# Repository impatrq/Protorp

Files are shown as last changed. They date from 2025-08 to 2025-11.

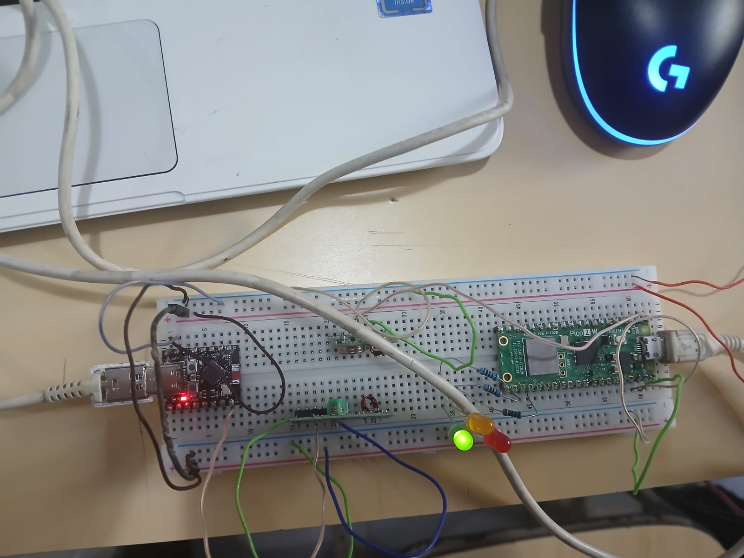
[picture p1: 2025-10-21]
fotos/pruebas en protoboard/prueba con una sola señal/ee414561-a399-4e3a-a274-134ad5745e3b.jpg

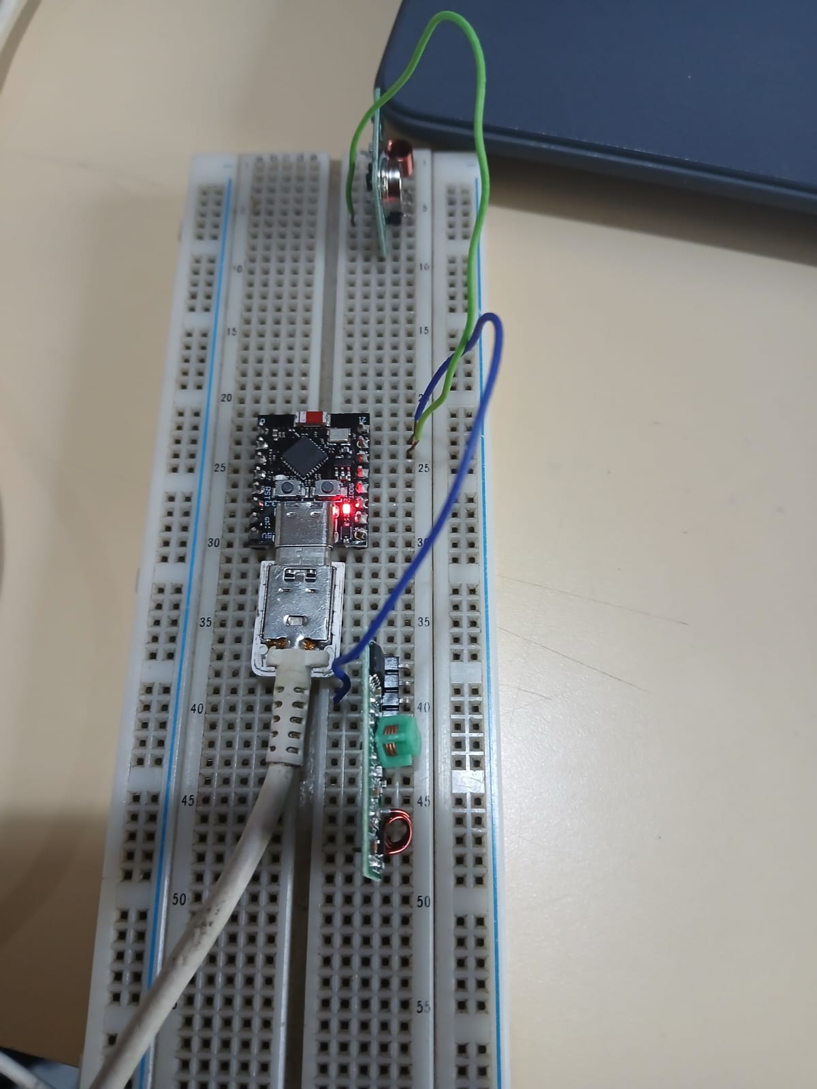
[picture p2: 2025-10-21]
fotos/pruebas en protoboard/prueba con una sola señal/pruebas con 2 señales/63338b9a-7119-42d7-b4c7-d0ca2e24c35b.jpg

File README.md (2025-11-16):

PROTORP 🚆

protorp y ahora sin png pero con png

🌟 Objetivo del Proyecto

PROTORP tiene como objetivo principal desarrollar sistemas de seguridad ferroviaria , como ATP (Automatic Train Protection) y ATS (Automatic Train Stop), a escala, para que pueda servir como entrenamiento y capacitacion para quien desee convertirse en señalero o maquinista, para que pueda ver las distintas situaciones que pueden ocurrir en las vias, sin tener que comprometer las formaciones reales ni sufrir accidentes durante el proceso de entrenamiento.

💡 ¿De dónde surgió la idea?

La idea de PROTORP nació de la necesidad de mejorar la seguridad y eficiencia en los sistemas ferroviarios, ademas de servir como capacitacion y entrenamiento, sin comprometer las formaciones reales ni sufrir accidentes, durante el proceso de entrenamiento, evitando costos asociados a refacciones y recuperacion de los afectados.

🛠️ Descripción del Proyecto

Nuestro proyecto incluye:
- Sistema ATS: Detiene automáticamente el tren si se salta una señal de advertencia.
- Sistema ATP: Controla la velocidad y la distancia entre trenes para evitar colisiones.
- Modelo a escala: Incluye señales y cambios de vía.

⚙️ Componentes a Utilizar
| Componente | Descripción | 
| Microcontroladores | ESP32| 
| LEDs | LEDs infrarrojos| 

🚀 Servicios que ofrece PROTORP
- Seguridad y prevención de accidentes: El sistema ATS actúa como un mecanismo de emergencia para frenar trenes que no respetan las señales.
- Eficiencia en el flujo de trenes: El sistema ATP organiza las formaciones para mantener distancias seguras y evitar demoras.
- Capacitación profesional: Permite entrenar maquinistas en un entorno seguro, reduciendo riesgos y costos.

👥 Equipo

Fernando Gonzalez: 





Santiago Vila: 


## 📬 Contacto


Pagina Web: https://protorp2025.netlify.app/

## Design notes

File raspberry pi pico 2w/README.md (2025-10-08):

**Comunicación RF entre Raspberry Pi Pico y ESP32**

Este repositorio se basa el desarrollo de un sistema de señalización ferroviaria, basado en comunicación por radiofrecuencia entre una Raspberry Pi Pico (a la cual va conectada un transmisor) y una ESP32 ( a la cuel se conecta un receptor). El objetivo es simular el estado de vías (LIBRE, PRECAUCIÓN, OCUPADO).

**¿Por qué se borró esta carpeta varias veces?**

Durante el proceso de testeo se realizaron varias modificaciones del código para la RASPBERRY y se elimino esta carpeta algunas veces. La razon principal es que pasamos de usar comunicacion entre una Raspberry en la locomotora y otra en la via, a cuna comunicacion usando una ESP32 en la locomotora y una Raspberry en la via y usando sensores RF433MHZ, por lo que los viejos codigos quedaron desactualizados 

Este README se creo con la finalidad de explicar porque se borro la carpeta varias veces y se eliminaron varios codigos. Esta carpeta contiene la libreria que se uso, los cambios importantes se realizaran en el codigo llamado main.py. La siguiente actualizacion en ese codigo se hara para incluir 2 transmisores y 2 receptores en la Raspberry.

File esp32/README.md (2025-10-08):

**Comunicación RF entre Raspberry Pi Pico y ESP32**

Este repositorio se basa el desarrollo de un sistema de señalización ferroviaria, basado en comunicación por radiofrecuencia entre una Raspberry Pi Pico (a la cual va conectada un transmisor) y una ESP32 ( a la cuel se conecta un receptor). El objetivo es simular el estado de vías (LIBRE, PRECAUCIÓN, OCUPADO).

**¿Por qué se borró esta carpeta varias veces?**

Durante el proceso de testeo se realizaron varias modificaciones del código para la ESP32 y se elimino esta carpeta algunas veces. Algunas razones son:

- Se pasó de una estructura básica de recepción a una más modular, con codificación de velocidad e ID.
- El receptor RF original con el que lo probamos tenía fallas, lo que llevó a problemas en la recepción y ajustes innecesarios en el código.
-  Se eliminaron versiones redundantes, pines mal asignados y funciones que no se usaban en la prueba actual.
- La ultima razon es que los codigos originales se hicieron para que la ESP32 y la raspberry se comunicaran por WIFI, pero la gracia es que se manden los datos por los transmisores y receptores de 433MHZ para poder usarlos como baliza y sensar el paso del tren cuando pasa por la via, y que la raspberry se comunique con WIFI y poder mostrar toda la informacion que tienen las señales conectadas  a las raspberrys en la pagina web     

Este README se creo con la finalidad de responder a esa pregunta. A partir de ahora se añadiran las librerias que se usaron y como probar el codigo, pero los cambios importantes se realizaran en el codigo llamado main.py.
El codigo qmain.py que esta actualmente, a fecha de creado este Readme, se hizo de esta manera para probar un transmisor en la Raspberry y un receptor en la ESP32. El siguiente cambio que se hara en el codigo sera para que el ESP32 tenga un transmisor y un receptor y la Raspberry tenga 2 transmisores y 2 receptores.

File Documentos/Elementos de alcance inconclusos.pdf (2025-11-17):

ELEMENTOS DE ALCANCE INCONCLUSOS

Nuestra principal problematica fue que iniciamos un poco tarde el desarrollo del proyecto ya que, en primera instancia, nos contactamos con un trabajador y un pasante de la empresa SIEMENS MOBILITY. Contabamos con que la empresa nos iba a conceder los fondos para el proyecto, pero la fundacion de la empresa rechazo darle los fondos a las personas con las que nos contactamos y ellos tardaron mucho tiempo en avisarnos. Por lo mismo, se nos dificulto la adquisicion de la locomotora y las vias.

El siguiente problema fue que compramos sensores RF de 433mhz. Hicimos varias pruebas entre ellos con distintos lenguajes y plataformas de programacion(Arduino, Thonny y VScode), ya sea con ESP32 o con Raspberry Pi en Thonny, y el principal problema fue que el transmisor mandaba el mensaje pero el receptor nunca lo recibia, a pesar de estar a una minima distancia, por lo que no pudimos demostrar el funcionamiento de los semaforos y tampoco pudimos hacer que las raspberrys mandaran el estado de los semaforos a la pagina web (ya que al principio queriamos que en la pagina hubiera una seccion que mostrara las distintas formaciones que estaban en el hardware.)

Por ultimo, creemos que no pudimos trabajar mejor en solucionar estos errores debido al numero de integrantes del equipo(2), lo que hizo dificil la distribucion y atencion de las tareas (un ejemplo de esto es nuestra pagina de instagram, en la cual subiamos mayormente historias pero no muchas publicaciones).

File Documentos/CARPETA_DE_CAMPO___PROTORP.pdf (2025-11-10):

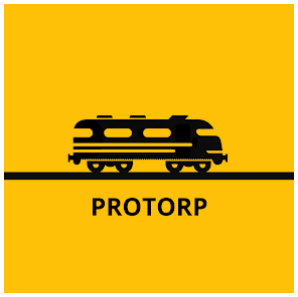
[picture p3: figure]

# PROTORP

## Carpeta de Campo

## Año de desarrollo: 2025

## E.E.T. Nº7 de Quilmes

Sitio web: https://protorp2025.netlify.app/

Trello: https://trello.com/b/dudjmzhY/kanban

GitHub: https://github.com/impatrq/Protorp

Redes sociales: @protorp25 (https://www.instagram.com/protorp25/)

Escuela de Educación Técnica Nº7 “Taller Regional Quilmes” Especialidad: Electrónica

Año lectivo: 2025

## Índice

1. Equipo | 2
2. Objetivo del Proyecto PROTORP | 2
Objetivo del Proyecto PROTORP | 2
Documentación Día a Día | 3

## 1. Equipo

## Integrantes del proyecto PROTORP

Joaquín Gonzalez Nogueira | Santiago Nicolás Vila

## 2. Objetivo del Proyecto PROTORP

El proyecto PROTORP (Protección y Regulación de Trenes mediante Organización y Respuesta Programada) tiene como objetivo principal el desarrollo de un sistema automático de protección ferroviaria (ATP) y un sistema de frenado automático (ATS) a escala, combinando hardware y software en un entorno educativo.
El propósito es crear una maqueta funcional que simule un circuito ferroviario real, con señales, cambios de vía, sensores de ocupación y control mediante microcontroladores como ESP32 y Raspberry Pi.
Además, el sistema busca representar cómo la tecnología puede mejorar la seguridad, eficiencia y automatización en el transporte ferroviario, estableciendo un puente entre la educación técnica y las soluciones tecnológicas reales aplicadas al ámbito ferroviario argentino.

## PROYECTO PROTORP: DOCUMENTACIÓN DÍA A

## DÍA

### ABRIL

14/4: Creamos la cuenta de instagram y Santiago empezo a comunicarse con sponsors. 15/4: Joaquin empezo con la programación de la página web y Santiago con la búsqueda de sponsors.
16/4: Joaquin continuo con la programación de la pagina web, y Santiago con búsqueda de sponsors.
17-20/4: Feriado
21/4: Joaquin continuo con el desarrollo de la pagina web
23/4: Joaquin continuo con la pagina web
30/4: Joaquin continuo con la pagina web

### MAYO

7/5: Joaquin continuo con la pagina web
9/5: Joaquin continuo con la programación de la pagina web
Semana del 12/5 a 18/5: Ambos tuvimos una reunion con SIEMENS, leimos la documentación y Joaquin continuo la programación de la pagina web
Semana 19/5 a 25/5: Tuvimos una segunda reunion con SIEMENS para hablar sobre nuestras dudas y Joaquin termino la programación de la pagina web, consiguio un link en Netlify.app y Santiago la subio al Instagram
Semana 26/5 a 1/6: Santiago realizo un diagrama del funcionamiento de las vías y Joaquin añadio un poco de información a la pagina ya que recibimos comentarios de que faltaba información

### JUNIO

Semana 2/6 a 8/6: Esta semana nos dedicamos a preguntarle a distintos profes sobre que componentes usar y a empezar con unas reformas en la pagina web
Semana 9/6 a 15/6: Santiago realizo la lista de materiales y la mando a la empresa, mientras Joaquin siguio con las reformas en la pagina web
Semana 16/6 a 22/6: Joaquin instalo Blender y aprendio a usarlo para poder realizar el modelo 3D de la señalizacion de los cambios de via
Semana 23/6 a 29/6: Joaquin realizo el modelo 3D de la primera señal y la subio al Github como STL

### JULIO

16/7: Tuvimos una reunion sobre los avances del proyecto. Nos sugirieron trabajar durante el receso invernal para ganar tiempo y pedirle los componentes a cooperadora. 18/7: Fuimos a pedir 2 Raspberrys Pi Pico 2W y 2 modulos RF de 433mhz a Cooperadora. Tambien nos prestaron resistencias y LEDs del pañol.
Receso Invernal: Joaquin estuvo haciendo simulaciones en Wokwi, que luego serian probadas en agosto.

### AGOSTO

4/8: Joaquin probo en Wokwi el modulo de comunicacion de tren - via y semaforos con 2 ESP32 y 3 leds.
5/8: Joaquin probo en Wokwi el modulo de sensor de ocupacion de via con un ESP32 y un led
6/8: Joaquin probo en Wokwi el funcionamiento de la señalización ferroviaria con un ESP32, un servo, un boton y 3 leds
8/8: Joaquin actualizo el sensor de ocupacion. Desde cooperadora nos mandaron llas 2 Raspberrys que pedimos. Santiago subio una historia agradeciendole a cooperadora por las Raspberry y Joaquin instalo la configuracion de micropython en vscode para configurar la Raspberry.
11/8: Empezamos a hacer el diagrama eléctrico mientras inicializabamos la Raspberry en VScode.
13/8: A la mañana empezamos el curso de drones. A la tarde visitamos Retiro donde nos dieron una capacitacion y nos permitieron recorrer los andenes que estan en obra. 18/8: Joaquin empezo a preparar el codigo para que funcione el wifi de la Raspberry que ira en la via.
20/8: Este dia, a pesar de tener practicas profesionalizantes, no pudimos hacer nada porque se fue la luz y no pudimos cargar nuestras compus. Este dia tambien llegaron los sensores RF de 433 mhz de parte de cooperadora, entonces fuimos a retirarlos.
21/8: Joaquin termino de hacer el codigo de la raspberry que iria en la locomotora y probamos la comunicacion wifi entre ambas raspberry
27/8: Tuvimos el curso de dron
28/8: Tratamos de probar la raspberrys en fisico pero no tenian las patitas. Joaquin actualizo el codigo entre la Raspberry y la locomotora de la via

### SEPTIEMBRE

1/9: Santiago empezó a hacer un segundo modelo 3D de las señales ferroviarias ya que el primero tenia errores en el modelo
2/9: Santiago continuo con el segundo modelo 3D de las señales
3/9: Tuvimos curso de dron
4/9: Este dia ambos faltamos pero mandamos a imprimir una nota para llevar al Ferroclub Escalada y se la hicimos firmar al vicedirector Arguello
6/9: Este dia, a pesar de ser fin de semana y no tener practicas profesionaliantes, fuimos al Ferroclub Escalada con la nota. Este dia no habiamos llevado los componentes y nos dijeron que debian consultarle a la fundacion del Ferroclub por los materiales, asi que nos pidieron que volvieramos la siguiente semana con los componentes para darles una mejor explicacion de como iban a ir los componentes en el circuito
9/9: Santiago termino el segundo modelo 3D de las señales ferroviarias
10/9: Fuimos al curso de dron
13/9: Este dia volvimos al Ferroclub Escalada junto con los componentes. Les explicamos mejor el funcionamiento del circuito y como iban a ir montados los componentes. Nos dijeron que volvieramos la otra semana con otra nota para que nos den el material, pero nos confirmaron que nos iban a prestar una locomotora y un par de vías
16/9: Hicimos una lista de materiales y fuimos a pedirlos a cooperadora.
17/9: A la mañana estuvimos en el curso de drones. En la tarde Joaquin empezo a realizar el banner y Santiago el primer diseño de la placa en KiCad.
18/9: Joaquin termino de hacer el banner y Santiago continuo con el diseño de la placa en kicad
19/9: Santiago continuo haciendo el diseño de la placa en KiCad y le añadio una base al modelo en 3D
20/9: Santiago volvio al Ferroclub Escalada y le proporcionaron el tren y un par de vias 22/9: Probamos la corriente en las vias que nos proporciono el Ferroclub Escalada 23/9: Santiago soldao las patitas al ESP32 y continuo con el modelo en Kicad
24/9: Santiago finalizo el diseño en Kicad. Tambien, Joaquin empezo a hacer el codigo en una de las compus de la escuela ya que su compu andaba mal. Joaquin estuvo toda la mañana en el aula del profesor Montoni haciendo el codigo. A la tarde, el profesor Garabato nos proporciono mas vias, cambios de via y locomotoras para probar el circuito en fisico. Dedicamos un rato a ver que nos servia y que le podiamos devolver y luego Joaquin eempezo a instalar las librerias necesarias en Thonny y VScode para probar el codigo
25/9: Joaquin trato de probar el codigo del ESP32 en ARDUINO IDE pero no funciono. Tambien empezamos a limpiar las vias que nos dio el profesor Garabato y armamos el circuito para probar la corriente y verificar que el tren andara correctamente sobre las vias.
26/9: Continuamos limpiando las vias con virulana y alcohol. Este dia tambien nos mudamos a la jaula del fondo ya que se nos hacia incomodo armar y desarmar el circuito cada vez que queriamos probarlo, asi que decidimos llevar 2 mesas a la jaula y dejar las vias armadas ahi. Tambien Joaquin trato de probar la comunicacion wifi entre esp32 y raspberry en una de las compus de la jaula pero estas no tenian internet, asi que decidimos tratar de probarla en la comu de Santiago pero ahi tampoco funciono.
30/9: Este dia, Joaquin trato de probar por ultima vez el codigo en su compu con Platformio. El codigo se subio correctamente al esp32 pero al momento de abrir el serial monitor, este tardaba mucho en cargar o no mostraba nada. Finalmente, decidio probar el codigo del ESP32 y el de la Raspberry en Thonny

### OCTUBRE

1/10: A la mañana, pasamos el codigo de la Raspberry a Thonny y como aun no teniamos programada la esp32 para que mandara el estado de las vias, probamos mandandole mensajes desde una app llamada MyMQTT. A la tarde, Joaquin modifico el codigo del ESP32 para que mandara el estado de las vias.
2/10: Joaquin modifico el codigo de ambos componentes para incluir los leds y los sensores RF de 433mhz. Tratamos de probar el circuito en fisico pero nuestro cable no transmitia datos, entonces decidimos que lo probariamos el 7/10. Este dia, Santiago hizo la impresion del primer semaforo en 3D. El modelo 3D tenia una base aparte, asi que luego de imprimirlo en 3D, Santiago lijo y quito todo el sobrante, luego separo la base y la pego con la gotita. Por ultimo, luego de la escuela, fuimos a lo del señor Daniel Raley para conseguir mas vias rectas y otros 2 cambios de via. Nos proporciono un par de vias pero no nos pudo proporcionar los cambios de via que nos faltaban.
6/10: Este dia armamos el circuito para probarlo en fisico, pero nos dimos cuenta de algo importante. Los codigos originales se hicieron para que la Raspberry y la ESP32 se comunicaran por wifi, pero la gracia es que los datos se manden por los sensores de 433mhz. Luego de darnos cuenta de eso, Joaquin empezo a modificar todo el codigo de nuevo. Este dia, Santiago imprimio el segundo semaforo
7/10: Este dia, Santiago imprimio el 3er y 4to semaforo. Joaquin busco las librerias para poder programar los sensores de 433mhz junto con la Raspberry en Thonny. Las librerias que encontro para los sensores no eran compatibles con micropython, entonces le pidio a una IA que le cree una libreria para usar. Luego, empezo a programar nuevamente la ESP32 y la Raspberry con esta libreria. El codigo fue hecho para probar una sola señal 8/10: Este dia, Joaquin termino de programar la Raspberry y la ESP32 y tratamos de probar el circuito en fisico. Al principio no funciono ya que uno de los transmisores estaba dañado, luego lo intercambiamos con otro transmisor y funciono. El transmisor mostraba un estado entre “LIBRE”, “PRECAUCION” y “OCUPADO” en el shell de Thonny con la Raspberry y cambiaba el led dependiendo del estado. La ESP32 captaba este estado con su receptor y lo mostraba en el shell de Thonny que este fue recibido junto con la

velocidad simulada.
9/10: Este dia, Joaquin cambio el codigo para que se probaran dos señales en lugar de solo una. Luego empezamos el circuito con un ESP32, una raspberry, 3 TX y 3 Rx en 3 protoboards para probar su funcionamiento pero se nos hizo tarde y no pudimos prrobarlo, asi que lo probamos el dia 13/10
10/10: Este dia Santiago fue a la casa de un vecino a conseguir los cambios de via y vias rectas faltantes.
13/10: Este dia volvimos a armar el circuito en fisico para probarlo. No anduvo correctamente debido a que habia algunos errores en el codigo, mayormente relacionados a la logica de funcionamiento entre los componentes, asi que Joaquin empezo a modificar el codigo nuevamente para respetar esa logica.
14/10: Joaquin continuo modificando el codigo de ambos componentes y Santiago modifico el modelo en blender para que esta vez el modelo tuviera 2 semaforos y se pudieran imprimir mas rápido. Este dia tambien fuimos a cooperadora a solicitar un doble puente h driver l298n y unos pines hembra. Tambien teniamos pensado empezar a imprimir la placa pero este dia no estaba el profesor Fabricio Carlassara, que es el dueño de la fresadora y del software, asi que no pudimos imprimirlas.
15/10: Joaquin termino de armar ambos códigos. A la tarde, quisimos armar el circuito nuevamente, pero la profesora Lara necesitaba los protoboards, asi que probamos el circuito al dia siguiente.
16/10: Este dia armamos el circuito por ultima vez. El codigo parecia funcionar pero se nos quemo la raspberry porque accidentalmente pusimos 10volts en la fuente. Decidimos dejar de armar el circuito en protoboard cada vez que ibamos a probarlo para evitar accidentes como estos y empezar a armar la placa. Tambien, Joaquin a modificar el codigo para poder manejar la esp32 por bluetooth.
17/10: Joaquin continuo modificando el codigo para controlar la esp32(locomotora) por bluetooth, aparte de adquirir la libreria ble_simple_peripheral.py que es necesaria para que el esp32 se anuncie como un dispositivo bluetooth. Este dia tambien llego el driver l298 n asi que fuimos a buscarlo a cooperadora.
20/10: A la mañana no pudimos hacer mucho debido a que no habia wifi. A a tarde, Joaquin continuo con el codigo, añadiendole la logica de control del motor e incluyendole el driver l298n
21/10: Este dia, el profesor Fabricio Carlassara nos aconsejo cambiar el diseño en Kicad para hacer modulos de 1 raspberry en vez de tenerlas todas en una sola placa. Santiago modifico el diseño en KiCad y tambien corto la placa de cobre en nueve partes. Mientras tanto, Joaquin se instalo la app nRF connect para mandarle una velocidad aleatoria all esp32 desde la app y verificar que apareciera en el Thonny. Esta app tambien tiene una opcion de lectura que muestra las velocidades aleatorias que genera la esp32 en la app. Tambien instalo la libreria uwebsockets en la raspberry para coordinarla con la pagina web. Santiago rediseño el banner ya que nos parecio que el que hicimos antes quedo obsoleto, además que el anterior estaba en 90x120 px, lo que hacia que fuera muy pequeño, asi que en la segunda version tratamos de que saliera con la mayor calidad posible. 22/10: Santiago imprimio los semaforos 11 y 12 en 3D. Tambien imprimio la primera placa y la dejamos lista para soldar. Este dia tambien enviamos el banner al profesor Palmieri y luego de la escuela fuimos a retirar los pines hembra que compramos.
23/10: Santiago abrio en Blender el modelo 3D de los semaforos normales y tomo sus bases. Luego, las exporto al modelo 3D de los semaforos de cambio de via y se las añadio a ese modelo para poder imprimirlas con el fin de que tengan el mismo soporte que los semaforos normales. Luego fuimos a imprimirlos. Mientras tanto, Joaquin se enfoco en ver ejemplos de años pasados para realizar el manual de usuario, carpeta tecnica y video de presentación de la mejor manera posible. Tambien nos comunicamos con nuestro patrocinador SIEMENS para ver si nos podian proporcionar manuales de usuario para usar de inspiracion.
24/10: Joaquin realizo la carpeta del manual de usuario y empezo a programar el nuevo codigo de la raspberry
27/10: Joaquin continuo realizando el codigo de la raspberry y Santiago modifico el modelo del semaforo del cambio de via. Luego, Santiago imprimio el 13vo y 14vo semaforo en 3D
28/10: Este dia, Santiago imprimio los semaforos 15 y 16. Joaquin continuo el codigo de la raspberry y empezo a armar el texto del manual de usuario
29/10: Este dia fuimos a hacer pasantias a la empresa NEWTON. A la tarde, Joaquin continuo con el codigo de la Raspberry y con el texto del manual de usuario. Santiago armo el tren con el puente H, soldo algunas Raspberrys y lijo los sobrantes de los semaforos que imprimimos
30/10: Este dia, Joaquin termino el manual de usuario del proyecto implementado en un entorno real, pero nos recomendaron cambiarlo para que sea la explicación de la maqueta. Joaquin empezo con el nuevo texto y siguio programando las raspberrys. Mientras tanto, Santiago empezo a grabar tomas para el video presentación
31/10: Joaquin termino e el manual de usuario de la maqueta y ambos grabamos los audios para el video presentación. Santiago hizo todas las placas y se encargo de editar el video.

### NOVIEMBRE

3/11: Santiago agujereo todas las placas e hizo el modelo 3D de la cajita del motor. 4/11: Santiago armo todos los semaforos, con sus leds y sus cables. Joaquin empezo a hacer la carpeta tecnica.
5/11: A la mañana fuimos a NEWTON. A la tarde, Joaquin continuo con la carpeta tecnica y probamos el funcionamiento de la ESP32 y el driver por Bluetooth, observamos que al mandarle un valor se movia un poco y despues se detenia, decidimos cambiar los cables al dia siguiente. Mientras, nos pidieron rehacer el video presentación, asi que Santiago grabo nuevas tomas y se encargo de editar el video.
6/11: Probamos nuevamente el funcionamiento de la ESP32 por Bluetooth. Seguia pasando lo mismo que el dia anterior. Entonces, Joaquin trato de hacer una app por RemoteXY de Arduino, pese a que no le haya funcionado para programar antes. Instalo todas las librerias necesarias y se puso a hacer la app. Mientras, Santiago agujereo mas placas y probo el funcionamiento de uno de los semaforos junto con la Raspberry, que ya tenia el codigo cargado
7/11: A la mañana, Joaquin trato de seguir programando la app en arduino. Mientras, vino el profesor Medina y trato de ayudarnos a ver cual podia ser el problema. Santiago trato de armar nuevamente el circuito junto con el profe, mientras Joaquin le cargaba el codigo antiguo de Thonny al ESP32. Cuando lo probamos nuevamente, Santiago se dio cuenta que habia puesto la corriente de las vias al reves, entonces al invertirlo y mandarle valores por la app nRF connect, anduvo normalmente. Hicimos un par de pruebas mas pero la ESP32 se calento excesivamente. Le preguntamos al profesor Medina cual podria haber sido el problema, y junto con el verificamos que la ESP32 se habia quemado. Decidimos probar el codigo con la otra ESP32 que teníamos pero esta tambien estaba quemada, entonces Santiago pidio 2 ESP32 que llegarian el dia siguiente. Mientras, Santiago siguio armando las placas y los semaforos y Joaquin continuo con la carpeta tecnica y se puso a actualizar la carpeta de campo.

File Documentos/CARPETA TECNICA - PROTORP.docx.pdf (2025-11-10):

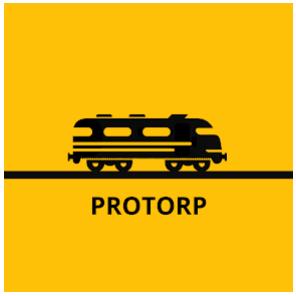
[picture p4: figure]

## PROTORP

## Carpeta técnica

Año de desarrollo: 2025

E.E.T. Nº7 de Quilmes

Sitio web: https://protorp2025.netlify.app/

Trello: https://trello.com/b/dudjmzhY/kanban

GitHub: https://github.com/impatrq/Protorp

Escuela de Educación Técnica Nº7 “Taller Regional Quilmes”

Especialidad: Avionica

## 1. Presentación del equipo

### 1.1 Integrantes del proyecto PROTORP

Joaquín González Nogueira

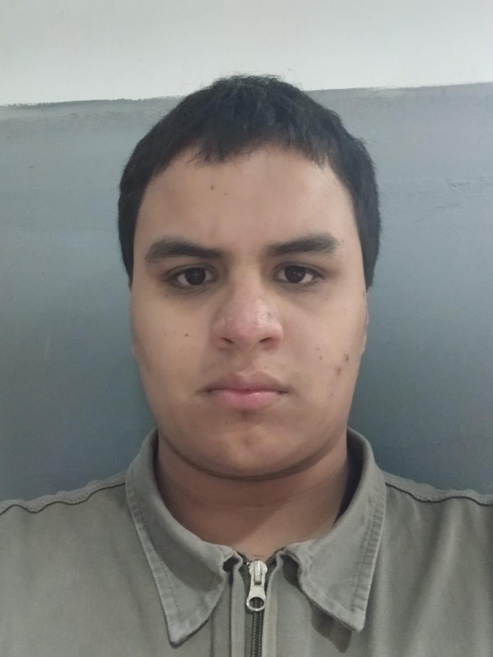
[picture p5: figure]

Santiago Nicolás Vila

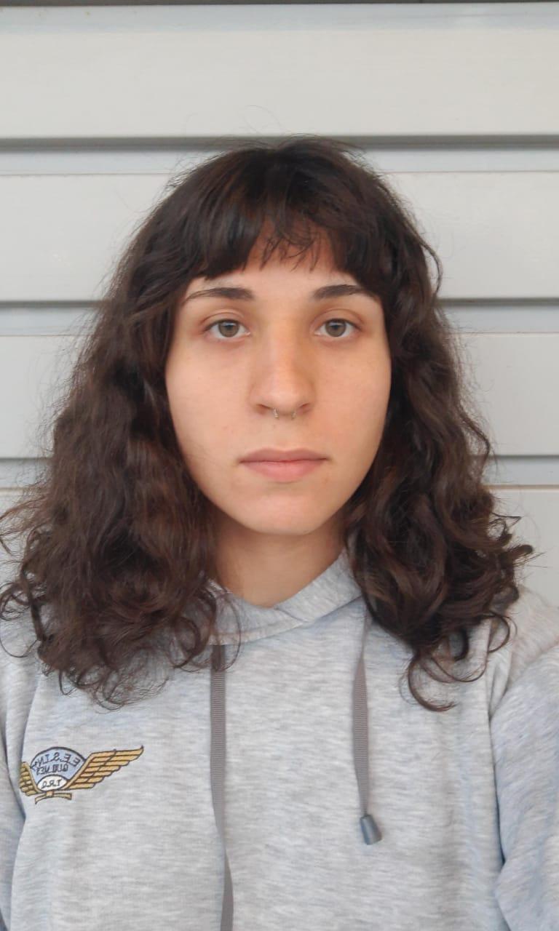
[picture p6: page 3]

### 1.2 Tiempo del proyecto

Cada integrante trabajó un promedio de 12 horas semanales en el proyecto.

## 2. Introducción

### 2.1 Objetivo del proyecto

PROTORP consiste en el desarrollo de los sistemas ATS (Automatic Train Stop) y ATP (Automatic Train Protection) a escala. Este proyecto tiene dos objetivos principales:

- Controlar las formaciones que circulan sobre la vía y la forma en la que se respetan los espacios para cada una, mejorando la seguridad del personal y reduciendo la posibilidad de errores humanos.
- Servir como entrenamiento para aspirantes a maquinistas, recreando distintas situaciones ferroviarias en un entorno seguro.

### 2.2 Descripción y Funcionamiento

La solución consiste en una maqueta ferroviaria que integra los principios de los sistemas ATS y ATP. El circuito reproduce un entorno ferroviario a escala, permitiendo controlar la circulación de los trenes y garantizar la seguridad de la operación.

### 2.4 Segmento destino y alcance

El proyecto está orientado principalmente a personas que deseen comprender el funcionamiento de los sistemas ATS y ATP en un entorno educativo y controlado. En cuanto al alcance geográfico, el sistema se proyecta a nivel nacional, dado que estos sistemas aún no se implementan ampliamente en Argentina.

## 3. Sistemas embebidos

### 3.1 Microcontroladores y microprocesadores utilizados

ESP32 (MicroPython)

Función: Controla la locomotora, gestiona el movimiento mediante un driver PWM, recibe comandos por BLE (NRF Connect) y transmite datos de velocidad y estado hacia las Raspberry Pi Pico mediante UART. Además, recibe señales RF433 MHz desde la vía para frenar o reducir la velocidad según la condición del tramo.

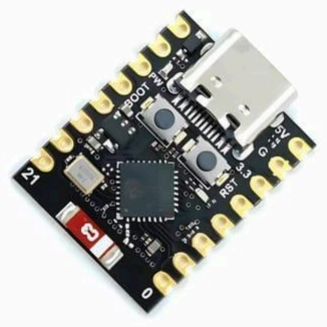
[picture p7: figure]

Raspberry Pi Pico 2W (MicroPython)

Función: Supervisa sensores de ocupación, controla semáforos (LEDs), comunica estados por Wi-Fi y envía datos a la locomotora vía RF433 MHz.

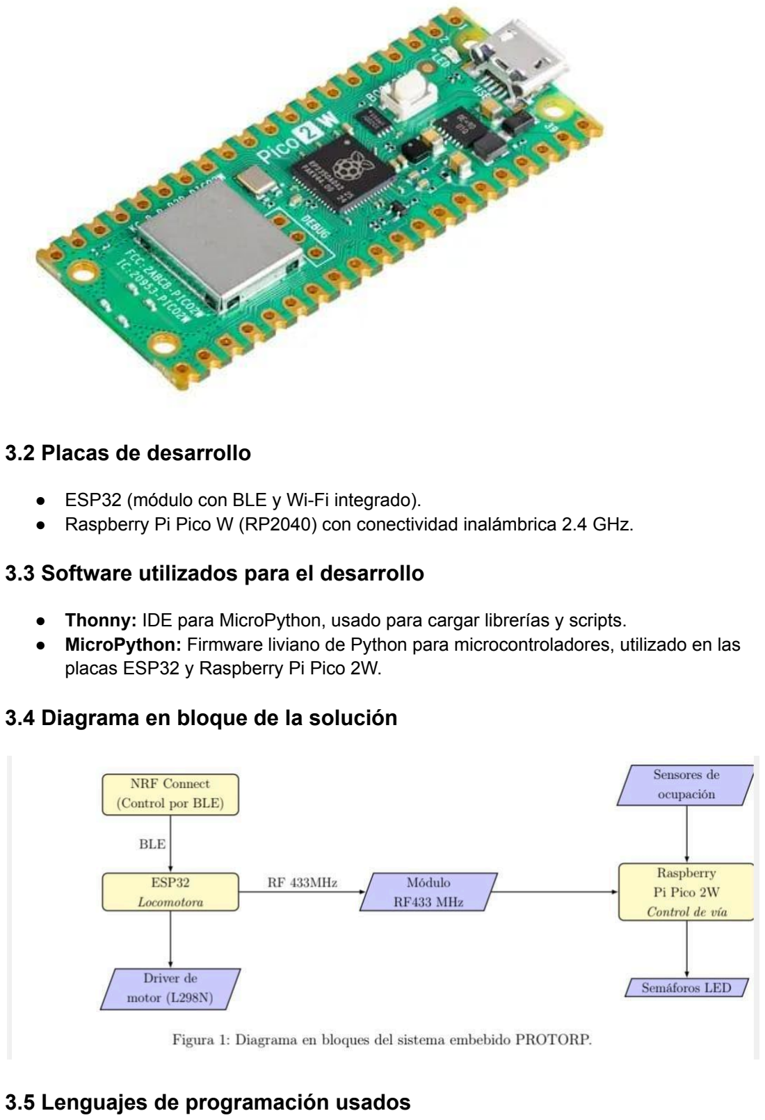
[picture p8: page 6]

### 3.2 Placas de desarrollo

- ESP32 (módulo con BLE y Wi-Fi integrado).
- Raspberry Pi Pico W (RP2040) con conectividad inalámbrica 2.4 GHz.

### 3.3 Software utilizados para el desarrollo

- Thonny: IDE para MicroPython, usado para cargar librerías y scripts.
- MicroPython: Firmware liviano de Python para microcontroladores, utilizado en las placas ESP32 y Raspberry Pi Pico 2W.

### 3.4 Diagrama en bloque de la solución

### 3.5 Lenguajes de programación usados

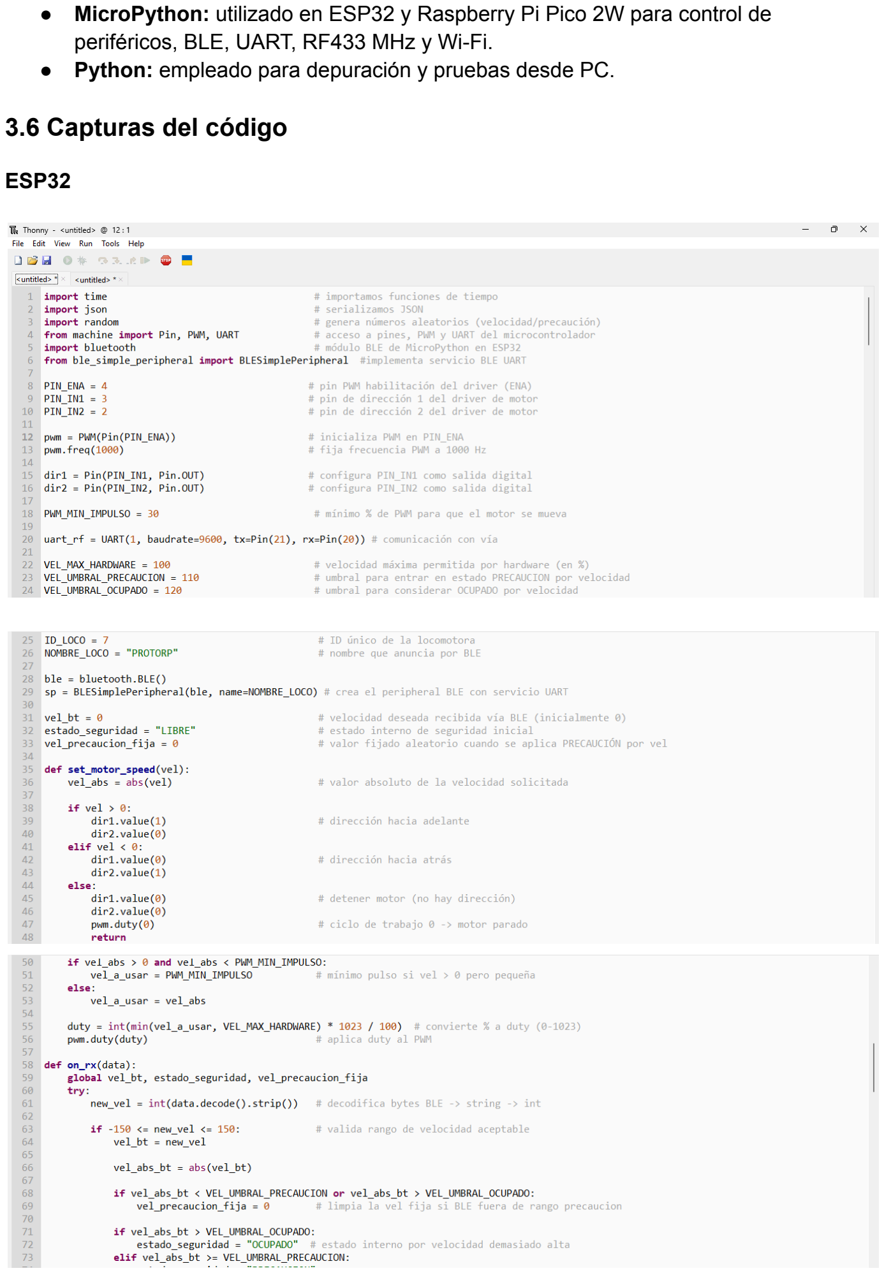
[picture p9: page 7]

- MicroPython: utilizado en ESP32 y Raspberry Pi Pico 2W para control de periféricos, BLE, UART, RF433 MHz y Wi-Fi.
- Python: empleado para depuración y pruebas desde PC.

### 3.6 Capturas del código

ESP32

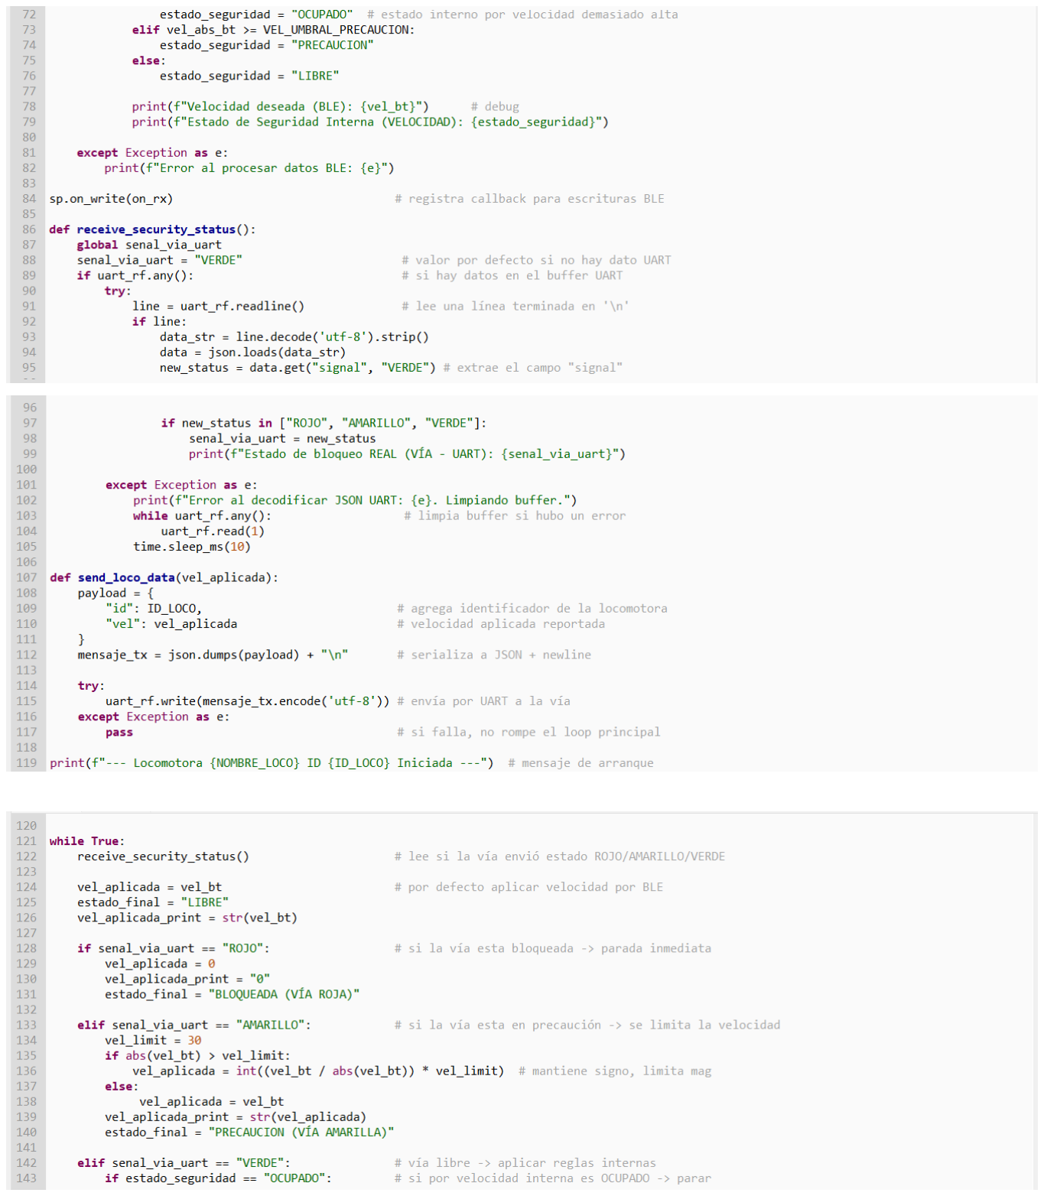
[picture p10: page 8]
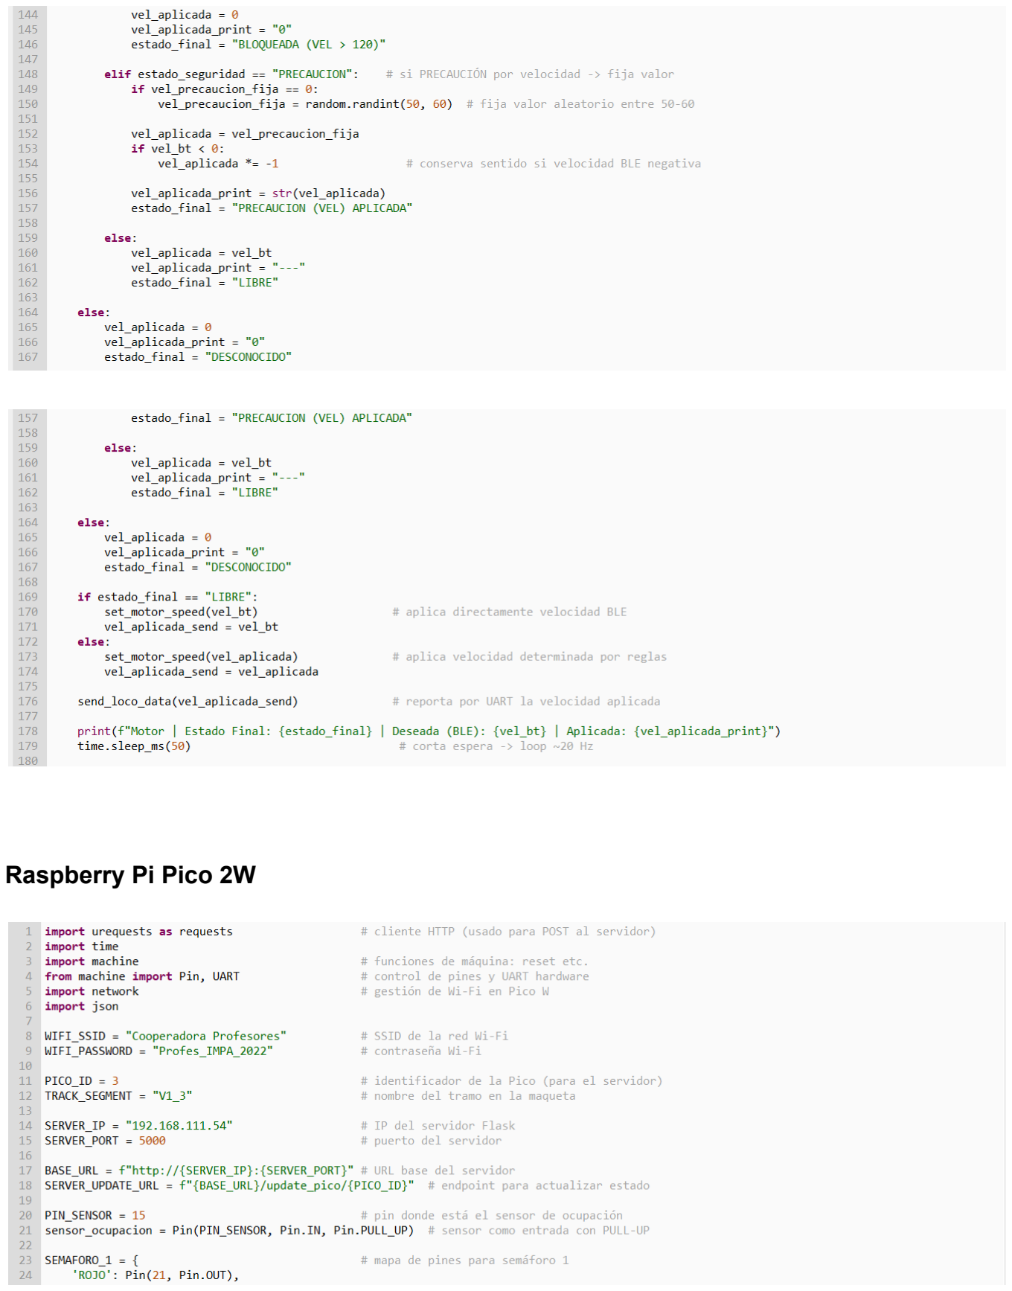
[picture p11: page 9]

Raspberry Pi Pico 2W

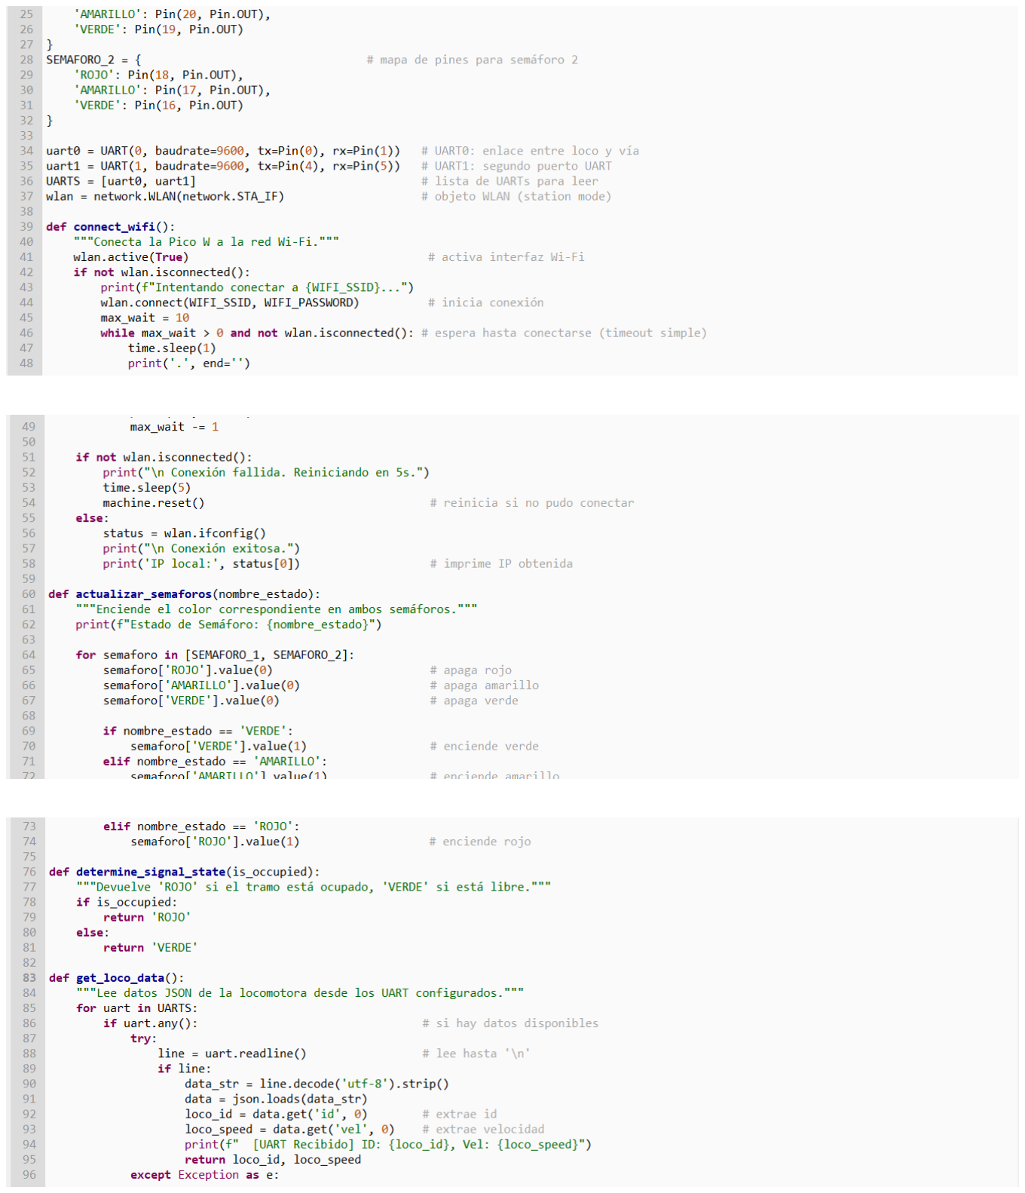
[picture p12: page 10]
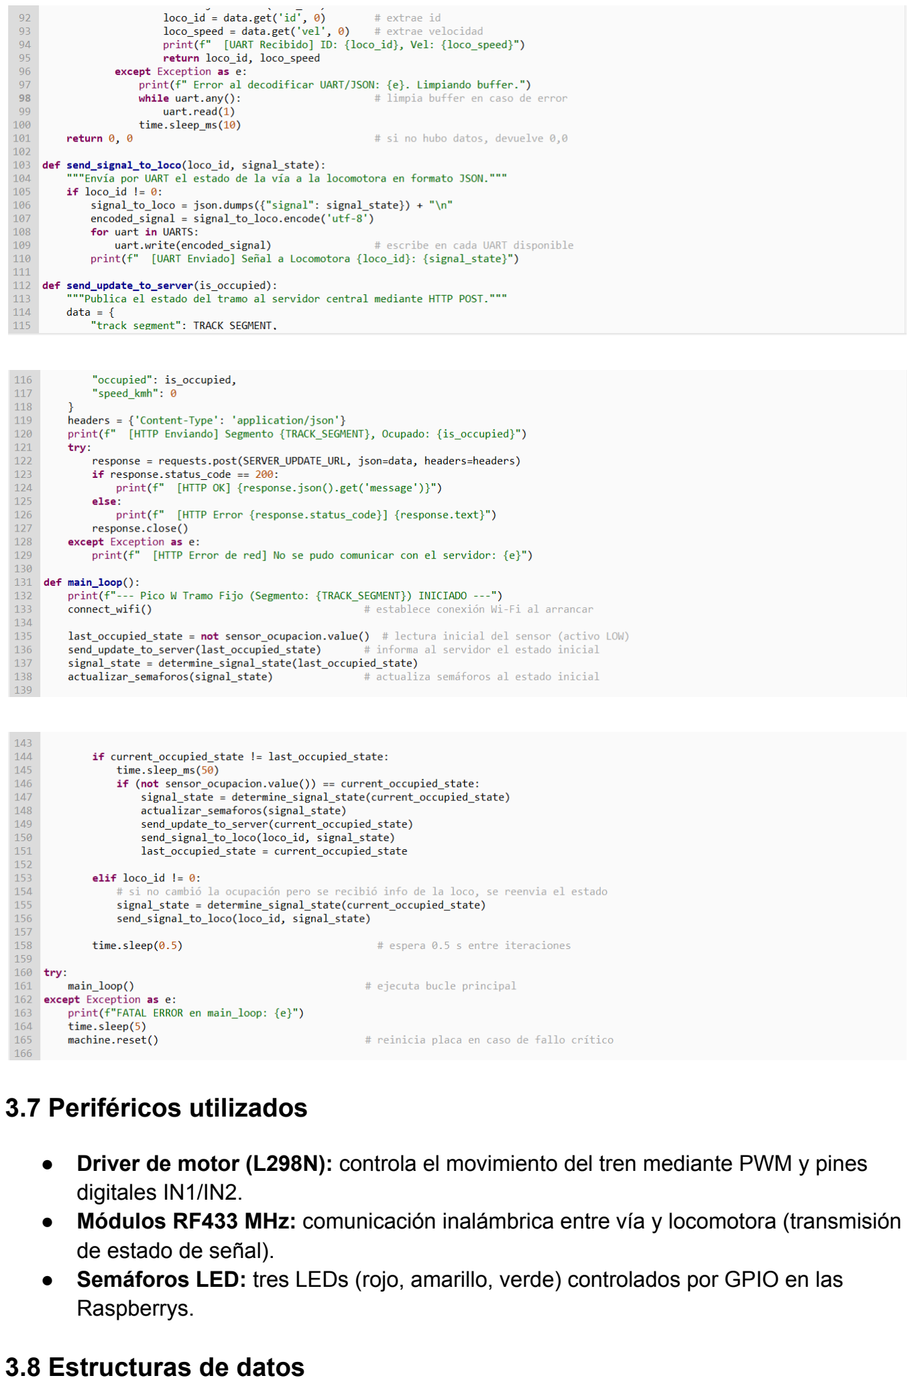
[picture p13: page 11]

### 3.7 Periféricos utilizados

- Driver de motor (L298N): controla el movimiento del tren mediante PWM y pines digitales IN1/IN2.
- Módulos RF433 MHz: comunicación inalámbrica entre vía y locomotora (transmisión de estado de señal).
- Semáforos LED: tres LEDs (rojo, amarillo, verde) controlados por GPIO en las Raspberrys.

### 3.8 Estructuras de datos

La comunicación entre dispositivos utiliza el formato JSON, que facilita la lectura y compatibilidad entre módulos.

Mensaje de la locomotora hacia la vía:
{
"id": 7,
"vel": 85
}
- Identifica la locomotora y su velocidad actual.

Mensaje de la vía hacia la locomotora:
{
"signal": "AMARILLO"
}
- Indica el estado del semáforo del tramo siguiente.
- Variables principales:
- vel_bt: velocidad recibida por BLE.
- estado_seguridad: modo actual de seguridad.
- sensor_ocupacion: determina si el tramo está ocupado.
- led_rojo, led_amarillo, led_verde: control de semáforos.

## 4. Electrónica

### 4.1 Software usado para esquemáticos y PCB

Para el diseño de los esquemáticos y PCB se utilizó el software KiCad 9. KiCad permitió desarrollar los diagramas eléctricos y los PCB, garantizando una adecuada organización del sistema electrónico del proyecto.

### 4.2 Fotos de cada PCB

PCB de la placa:

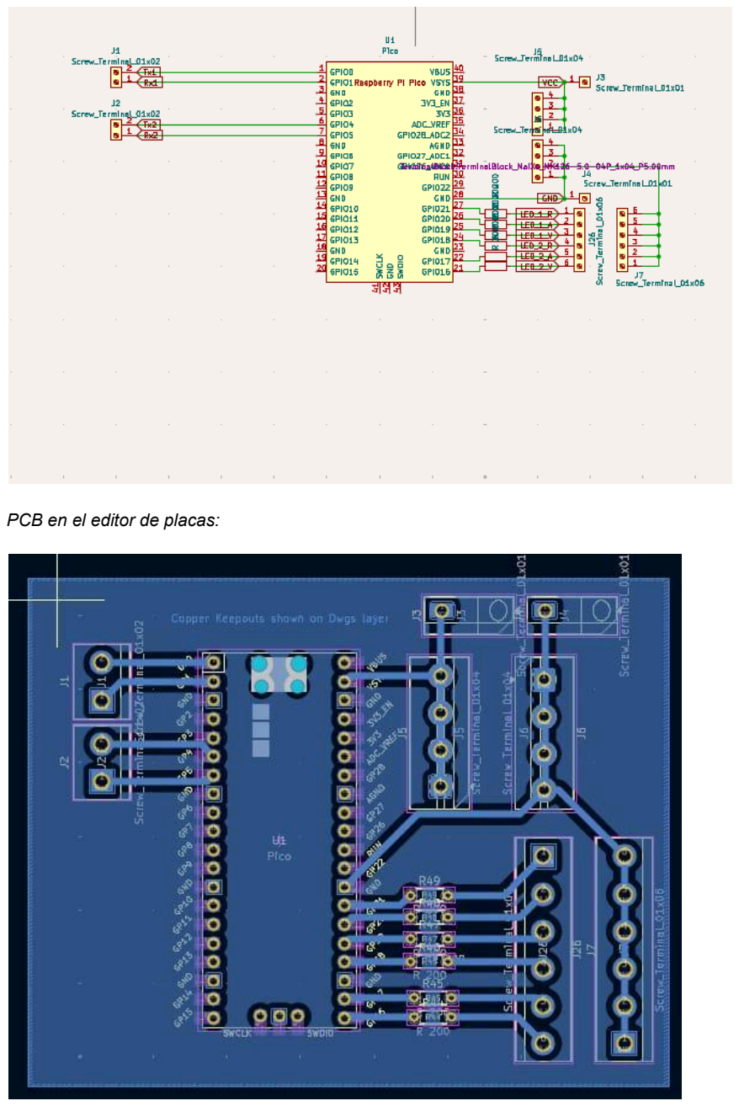
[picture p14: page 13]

PCB en el editor de placas:

Modelo 3D de la placa:

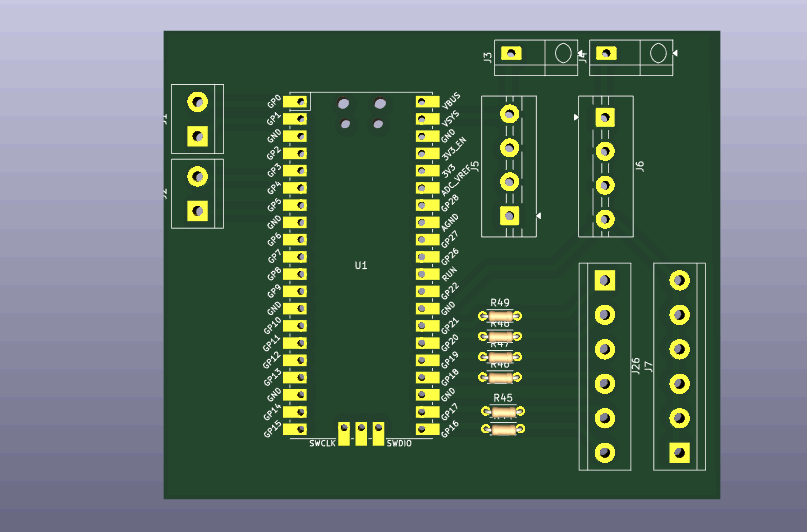
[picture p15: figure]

Placa en fisico:

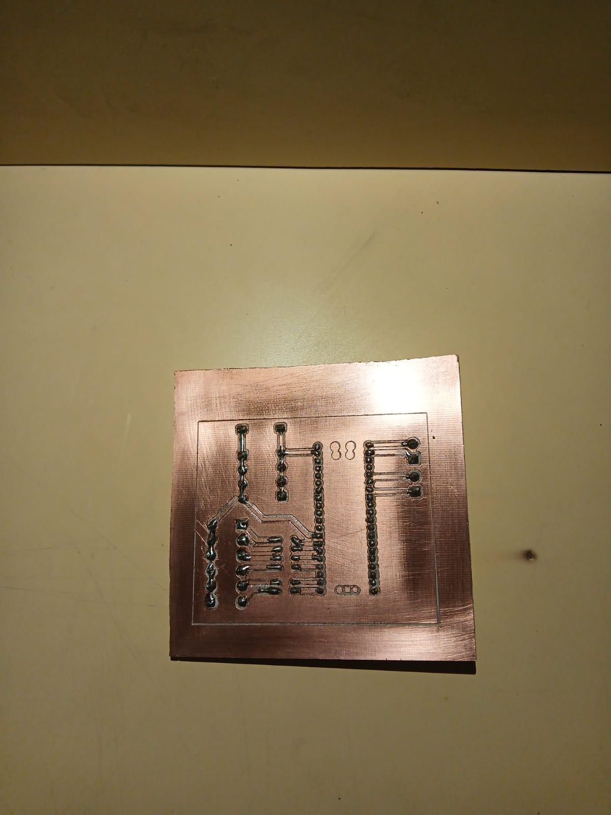
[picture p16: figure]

### 4.3 Especificación de fuentes de alimentación y potencias

La alimentación de la placa es de 5V con 10 amperes y una potencia total de aproximadamente 0.5 W por componente de control.

### 4.4 Datasheets

ESP32 datasheet: https://documentation.espressif.com/esp32-c3

Raspberry Pi Pico 2W datasheet: https://datasheets.raspberrypi.com/picow/pico-2-w-datasheet.pdf

Driver L298N datasheet:
https://www.handsontec.com/dataspecs/L298N%20Motor%20Driver.pdf

Módulos RF 433MHz datasheet: https://tecmikro.com/modulos-shields/326-modulo-rf-radiofrecuencia-433-mhz.html

## 5. Estructura

### 5.1 Software utilizados

Blender: Usamos Blender para hacer el modelo 3D de los semaforos, semaforos de cambio de via y el tender del motor.

Semaforo normal

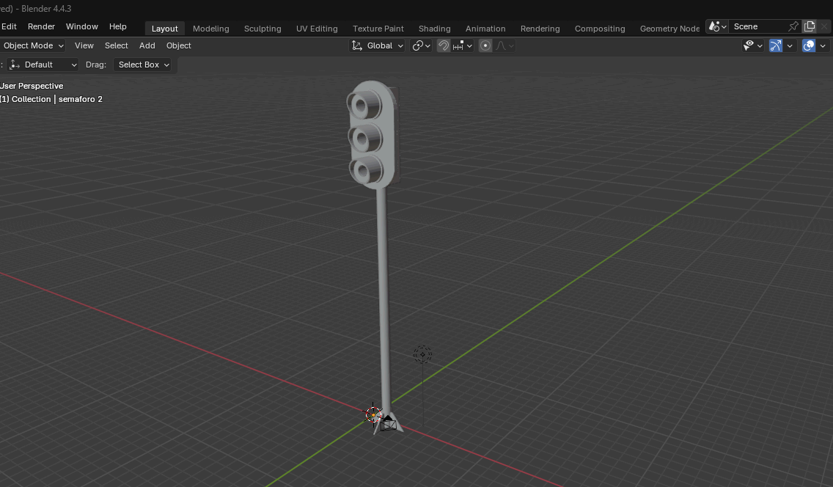
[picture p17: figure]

Semaforo del cambio de via

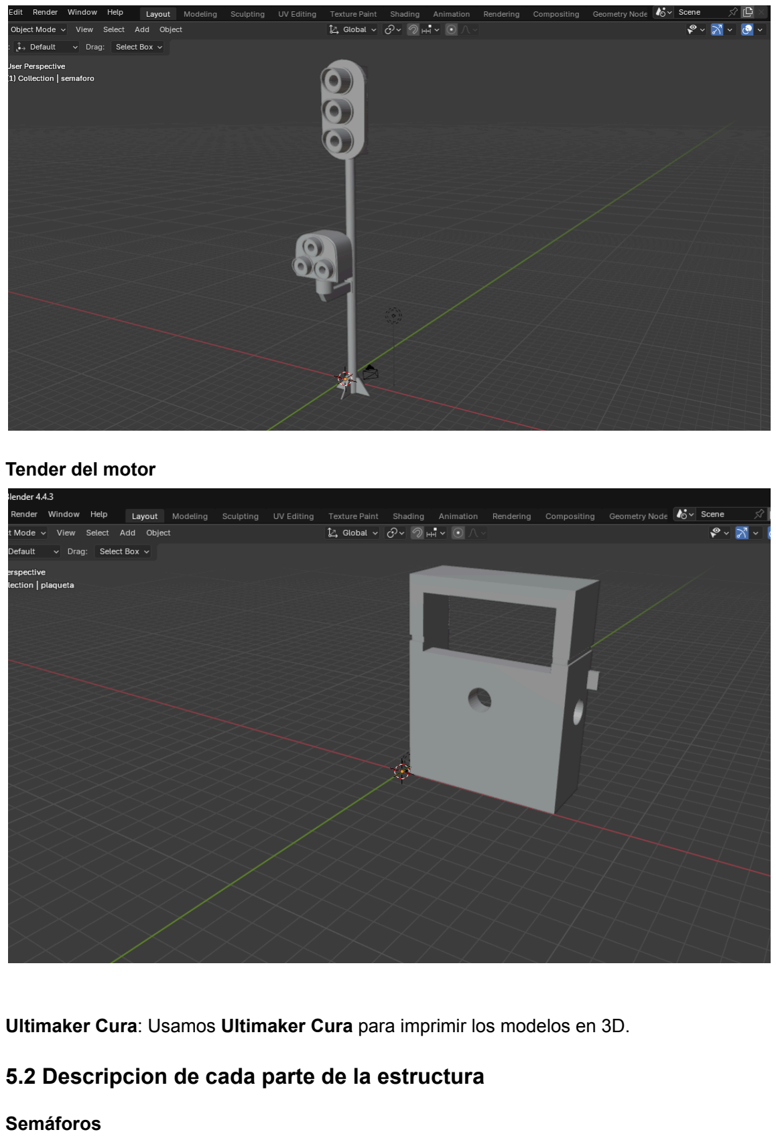
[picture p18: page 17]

Tender del motor

Ultimaker Cura: Usamos Ultimaker Cura para imprimir los modelos en 3D.

### 5.2 Descripcion de cada parte de la estructura

Semáforos

Existen dos tipos de semáforos. El primero es el semáforo regular, que cuenta con las luces roja, amarilla y verde. El segundo es el semáforo de cambio de vía, que es similar al anterior pero incluye una seccion de LED blancos. Estos LED indican la posición del cambio de vía, ya que están directamente conectados con los mecanismos eléctricos que controlan dicho cambio. De esta forma, el semáforo muestra en todo momento la posición real del desvío.

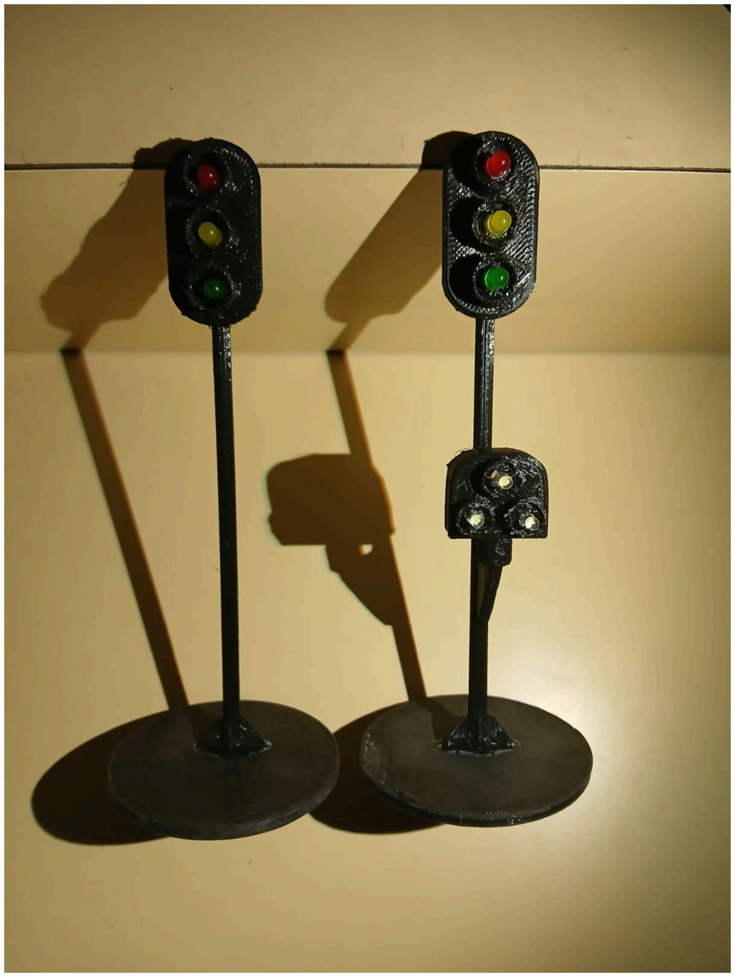
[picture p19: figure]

Vías

Las vias están son de escala H0. La maqueta está conformada principalmente por curvas y rectas, y cuenta con cuatro cambios de vía: dos hacia la derecha y dos hacia la izquierda. Estos cambios permiten realizar la rotación de la locomotora.Como se mencionó anteriormente, los cambios de vía están directamente asociados a los LED blancos de los semáforos de cambio de vía, lo que permite visualizar en todo momento la posición del desvío.

Vias rectas y curvas:

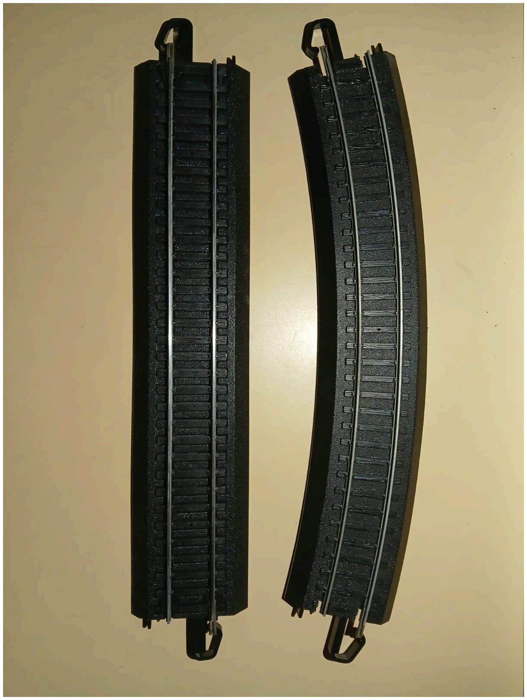
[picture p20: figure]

Cambio de via:

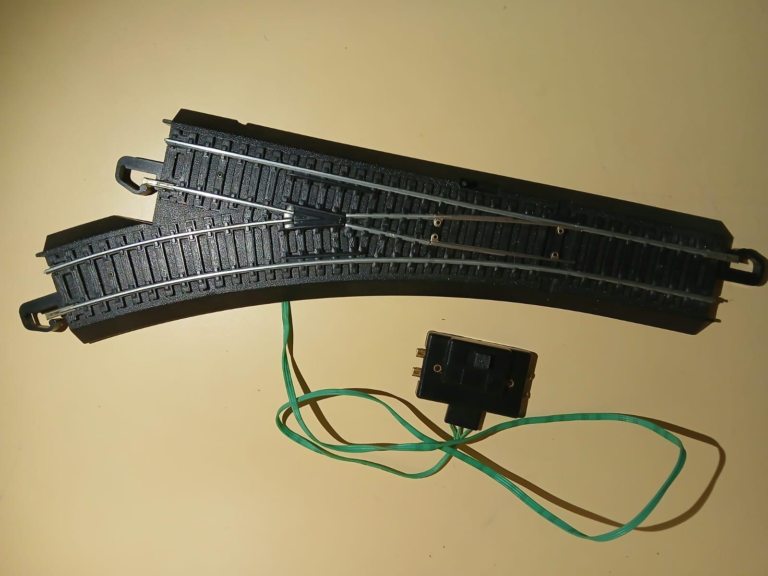
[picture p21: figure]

Locomotora

La locomotora circula sobre las vias H0. A traves de sus componentes, transmite su informacion y recibe el estado de la via, para determinar si puede seguir, si debe parar o disminuir su velocidad.

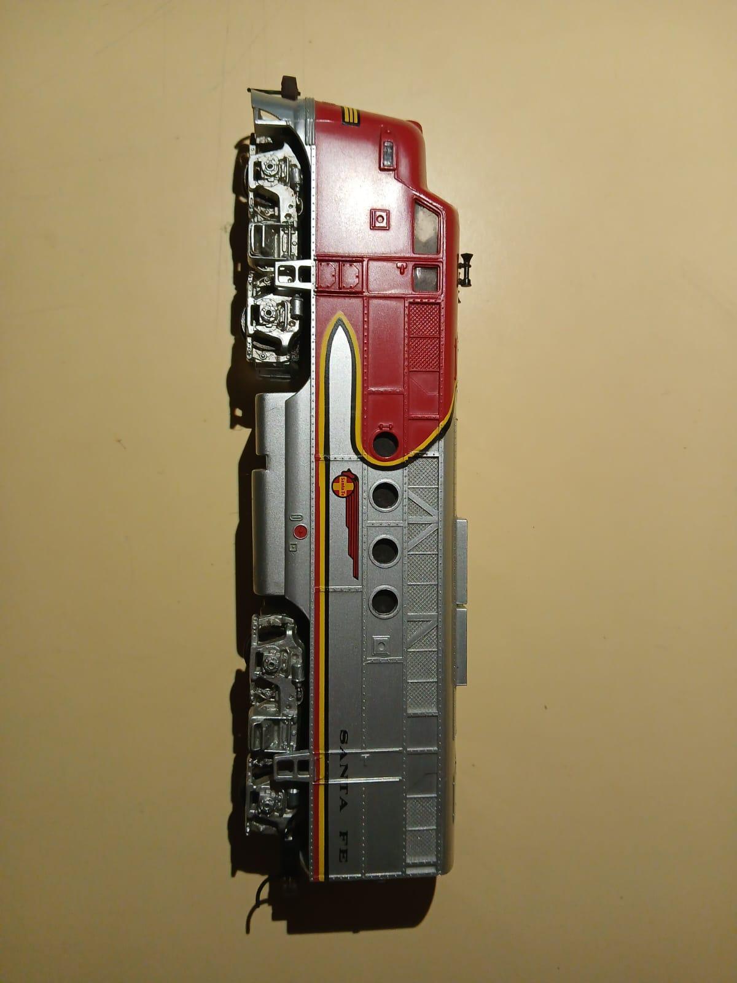
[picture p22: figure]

Potenciómetro

Esta maqueta se alimenta mediante un transformador de 16 V en corriente alterna (AC). Luego, la tensión se rectifica a corriente continua (DC), permitiendo regular el voltaje de la vía mediante un potenciómetro. El voltaje de salida puede variar entre 0 V y un máximo de

16 V en continua. Además, desde el potenciómetro, como se mencionó anteriormente, también se puede controlar la posición de los cambios de vía, ya que estos son eléctricos.

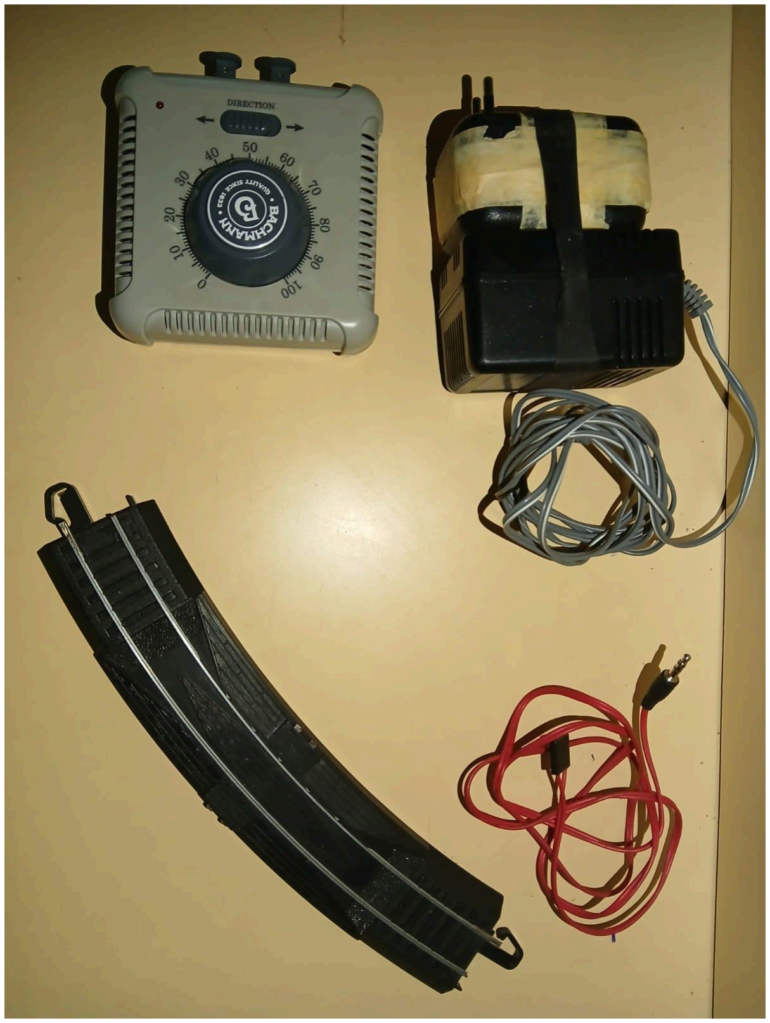
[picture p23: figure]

## 6. Bibliografia

Licitacion ADIFSE
https://plataforma.adifse.com.ar/uploads/archivo_adjunto/licitacion/20250401_094855-67ebe (https://www.google.com/search?q=https://plataforma.adifse.com.ar/uploads/archivo) 0b72a73b.pdf?v=2.1.70

ATS Linea roca: https://es.scribd.com/document/318056277/Ats-Linea-Roca

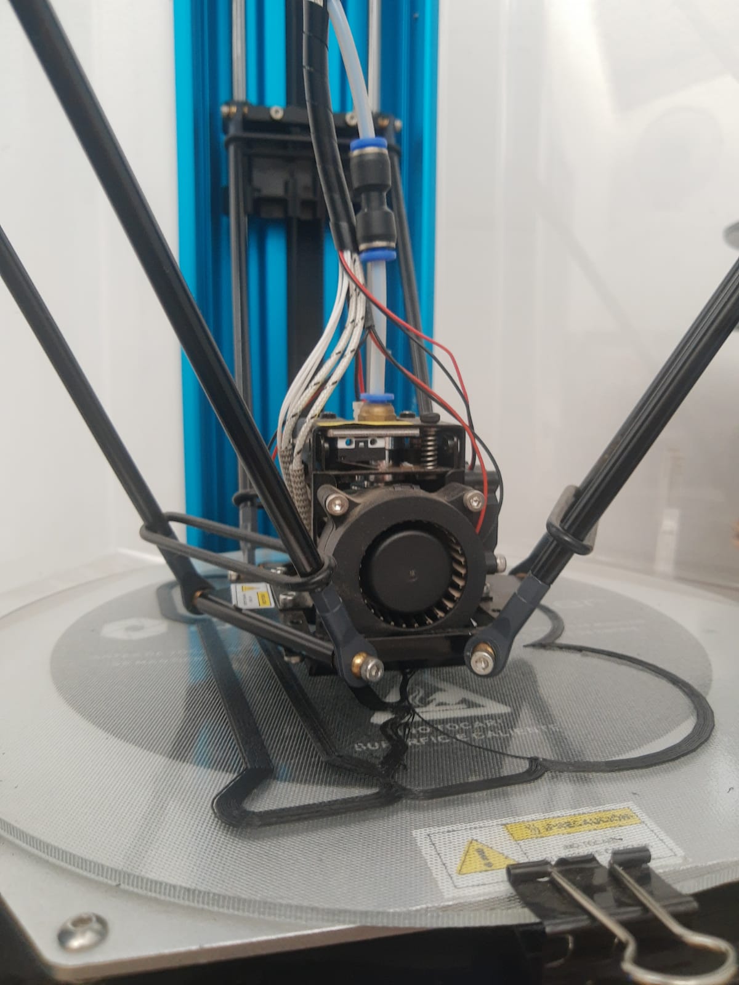
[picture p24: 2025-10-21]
fotos/impresiones 3D/ba639507-05fc-4772-ac8e-a2353a263247.jpg

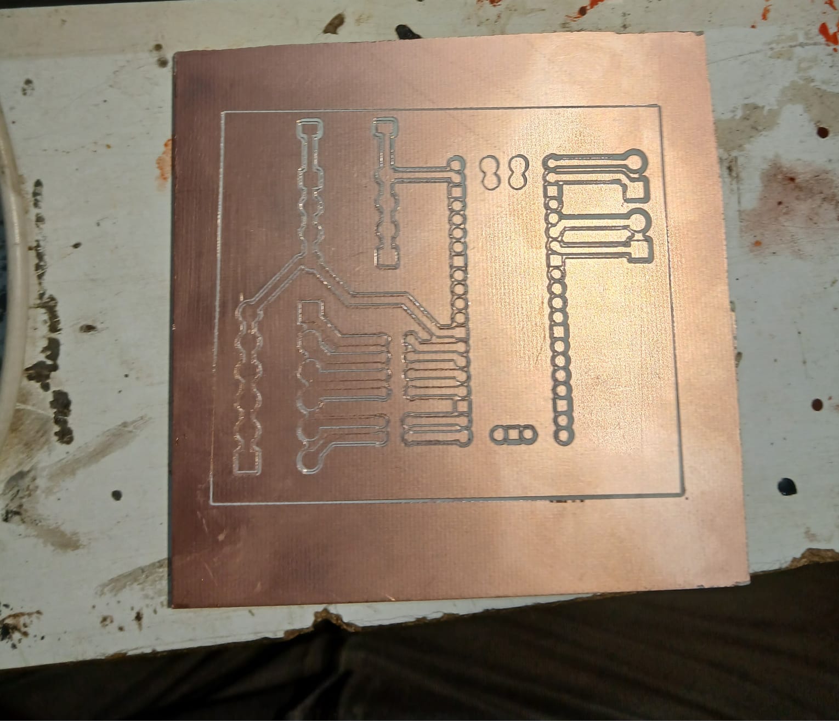
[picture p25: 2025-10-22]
fotos/placas de cobre/263e1a80-0259-446c-88bb-c691e8464f8e.jpg

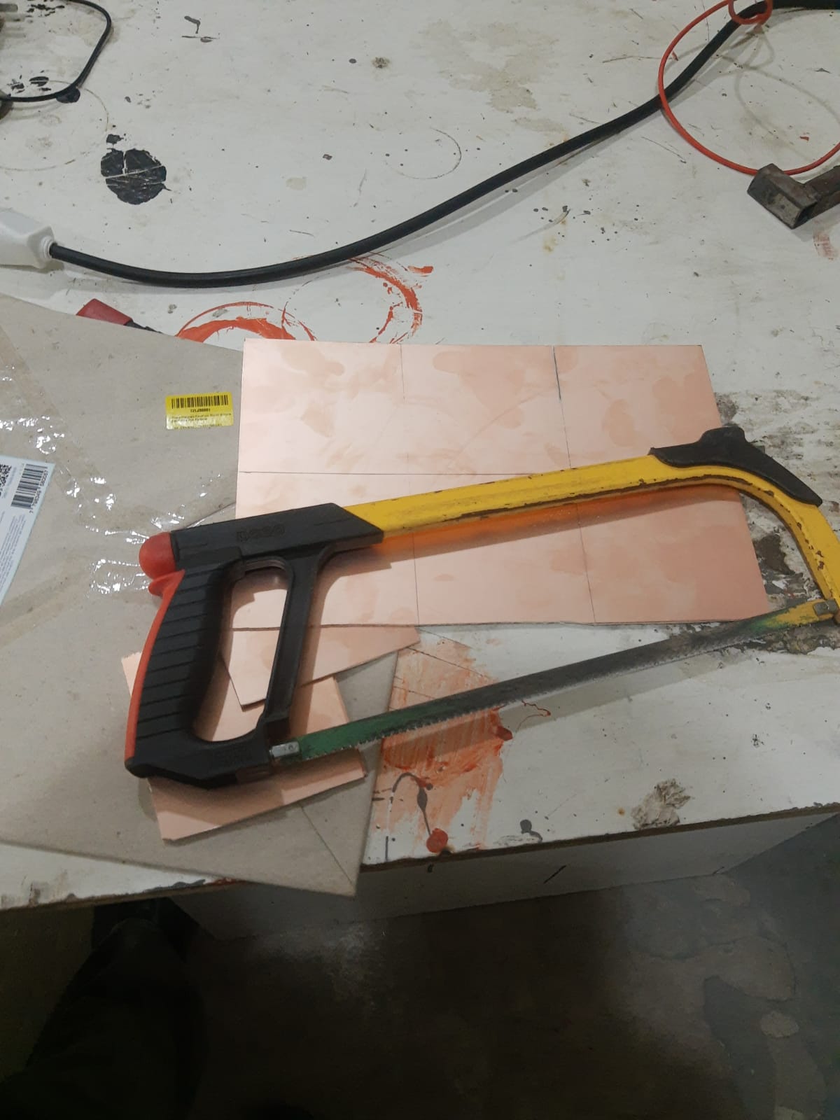
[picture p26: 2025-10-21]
fotos/placas de cobre/33694ae3-9141-43bc-b89a-788deed8c6ae.jpg

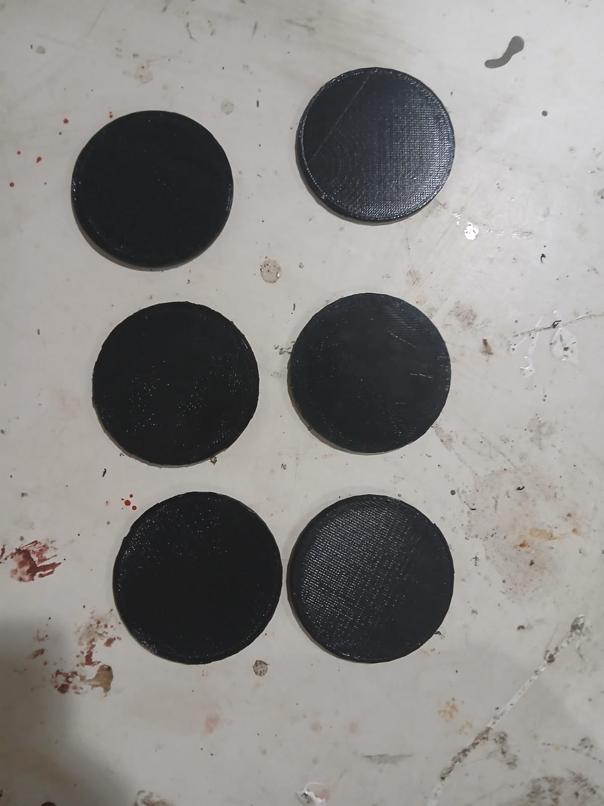
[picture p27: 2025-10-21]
fotos/impresiones 3D/eff81520-8f5c-479a-bd7d-48ed539483ca.jpg

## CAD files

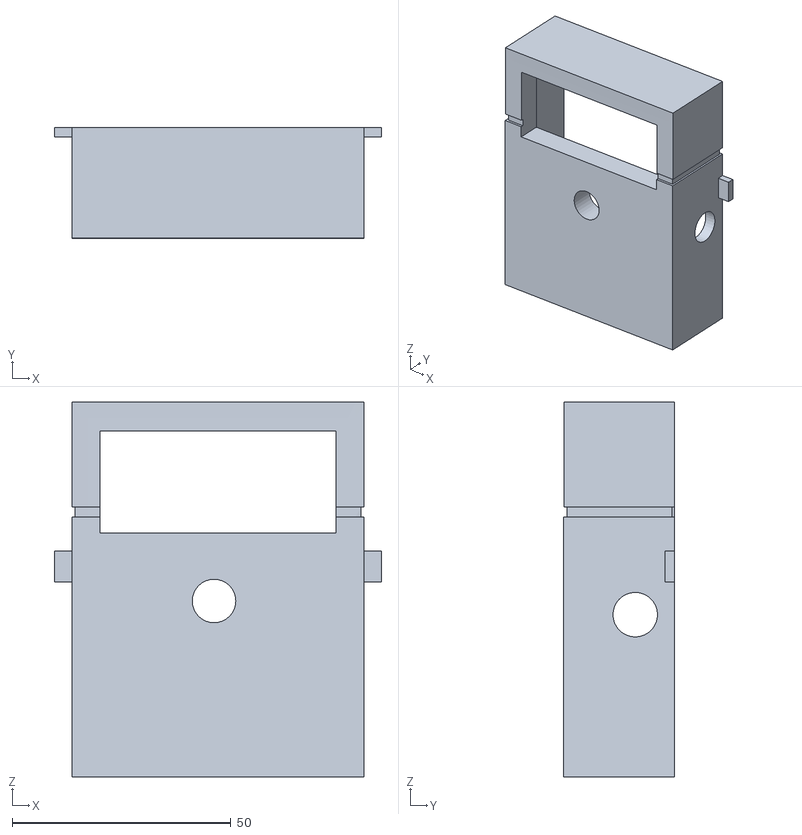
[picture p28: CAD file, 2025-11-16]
STL´s PROTORP/plaqueta.stl
74.8 x 25.4 x 85.7

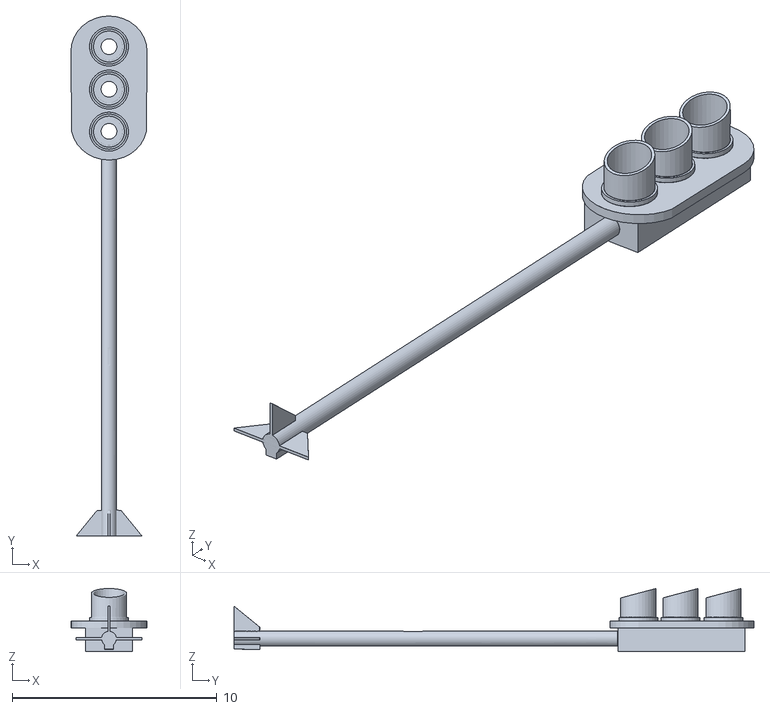
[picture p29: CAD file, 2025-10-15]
STL´s PROTORP/semaforo 4.stl
3.72 x 25.4 x 3.08

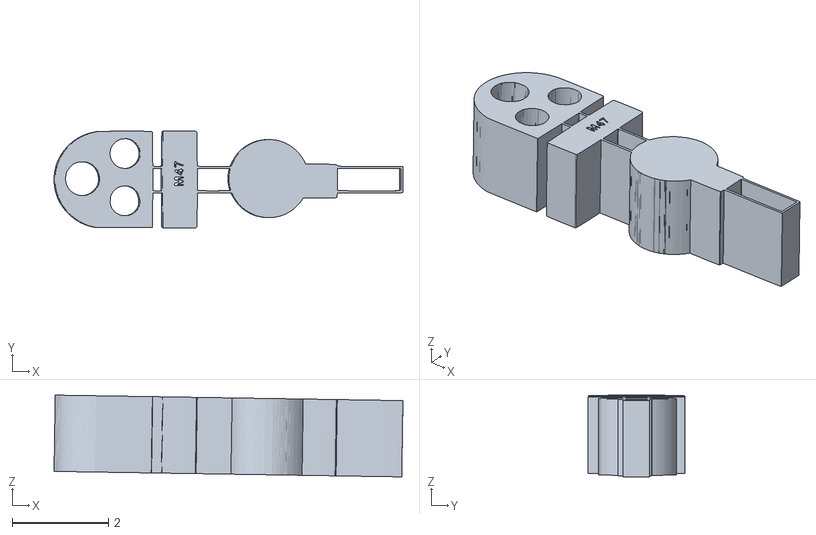
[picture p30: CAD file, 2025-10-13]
STL´s PROTORP/semaforo 1.stl
7.24 x 2.01 x 1.70

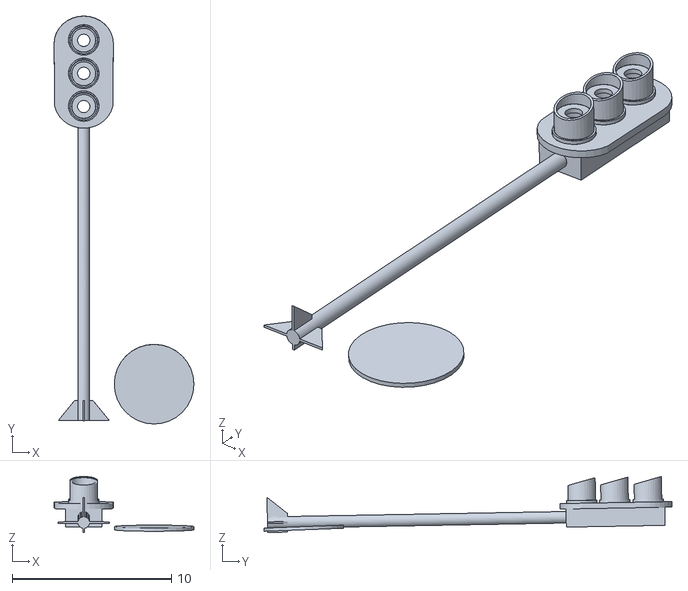
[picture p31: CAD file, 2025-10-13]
STL´s PROTORP/semaforo 3.stl
8.78 x 25.6 x 3.52

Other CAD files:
STL´s PROTORP/semaforo 2.stl

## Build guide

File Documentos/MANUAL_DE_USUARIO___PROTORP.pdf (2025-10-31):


# PROTORP

## Manual de Usuario

## Año de desarrollo: 2025

## E.E.T. Nº7 de Quilmes

Sitio web: https://protorp.com (https://protorp2025.netlify.app/)

Trello: https://trello.com/protorp (https://trello.com/b/dudjmzhY/kanban)

GitHub: https://github.com/protorp (https://github.com/impatrq/Protorp)

Redes sociales: @protorp (https://www.instagram.com/protorp25/)

Escuela de Educación Técnica Nº7 “Taller Regional Quilmes” Especialidad: Electrónica

Año lectivo: 2025

## Índice

1. Introducción | 2
2. Componentes | 2
3. Instalación del sistema PROTORP | 3
4. Control mediante la app NRF Connect | 4
5. Problemas o fallas comunes | 7

## 1. Introducción

### 1.1. Descripción de PROTORP

PROTORP es un sistema de protección (ATP) y freno automático (ATS) de trenes a escala. La maqueta cuenta con su propio sistema de señalización, control de vía, cambios de vía y panel mímico, con el fin de simular un entorno ferroviario a escala y representar de forma realista el funcionamiento ferroviario.

### 1.2. Objetivo

El objetivo de PROTORP es poder tener un control sobre las formaciones que circulan sobre la vía, y la forma en la que se respetan los espacios para cada una. Esto tiene como finalidad evitar colisiones o accidentes y asegurar un flujo constante de trenes. También está diseñado para que las señales sean automáticas y así reducir el trabajo del señalero.

### 1.3. ¿Por qué elegir PROTORP?

PROTORP está pensado para instruir a quien desee convertirse en maquinista, recreando las distintas situaciones que pueden ocurrir en las vías. Al ser un modelo a escala, se pueden observar y analizar diversos escenarios sin tener que probarlos en un tren real, eliminando por completo los riesgos de accidentes durante el proceso de entrenamiento.

### 1.4. Público destinado

PROTORP está destinado a personas que quieran convertirse en maquinistas o a quienes deseen entender el funcionamiento de los sistemas ATS y ATP en un entorno controlado y educativo.

## 2. Componentes

### 2.1. ¿Qué incluye PROTORP?

El sistema cuenta con los siguientes elementos:

Tren (locomotora): integrado con un microcontrolador ESP32 y un driver L298N que controla el motor.

8 Raspberry Pi Pico 2W.

Equipo de vías.

12 semáforos normales.

4 semáforos de cambio de vía.

Actuadores de cambio de vía.

LEDs rojos, amarillos y verdes.

### 2.2. ¿Qué se necesita para probar PROTORP?

Para probar el sistema, el usuario debe contar con:

Fuente de alimentación (de 5 a 12V).

Un teléfono móvil con Bluetooth y la aplicación NRF Connect instalada.

## 3. Instalación del sistema PROTORP

Para la instalación del sistema PROTORP, es fundamental realizar el montaje de las vías sobre una superficie plana y estable. Esto garantiza un funcionamiento correcto del tren y evita posibles descarrilamientos o errores de lectura en los sensores.

### 3.1. Montaje de vías

Comience montando los tramos de vía sobre la base. Algunos tramos vienen con señales luminosas incluidas, mientras que otros son tramos simples sin señalización. El montaje mínimo recomendado es de un tramo con señales y uno sin señales, aunque se aconseja instalar un tramo con señales cada dos tramos normales para evitar interferencias entre señales y reducir la posibilidad de entradas de ruido en los transmisores y receptores.

### 3.2. Distribución de controladores

Cada conjunto de dos tramos con señalización contiene una Raspberry Pi Pico 2W, encargada de supervisar el estado de las vías y transmitir esa información al sistema mímico. Los cables de cada Raspberry se conectan a los transmisores y receptores ubicados en los laterales de las vías, permitiendo la comunicación en tiempo real entre el mímico y la maqueta.

### 3.3. Conexión de alimentación

El sistema cuenta con un potenciometro, el cual regula la potencia general del circuito.

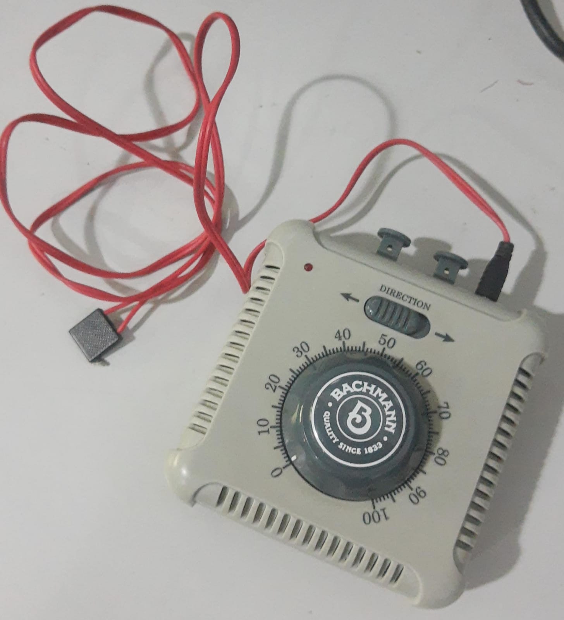
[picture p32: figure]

Se recomienda mantener el voltaje en su nivel máximo durante la operación, ya que el usuario puede controlar la velocidad del tren directamente desde su celular mediante la aplicación NRF Connect.
Antes de encender el sistema, verifique que:

Todas las vías estén correctamente encajadas para evitar descarrilamientos.

Los conectores estén firmes y sin falsos contactos.

Las señales luminosas respondan al encender el circuito.

Una vez comprobado todo, conecte el circuito a la fuente de alimentación y encienda el tren para iniciar la simulación.

## 4. Control mediante la app NRF Connect

La aplicación NRF Connect permite controlar el tren de forma inalámbrica utilizando el Bluetooth del ESP32.

### Pasos para usarla

1. Instale la app NRF Connect en su celular.

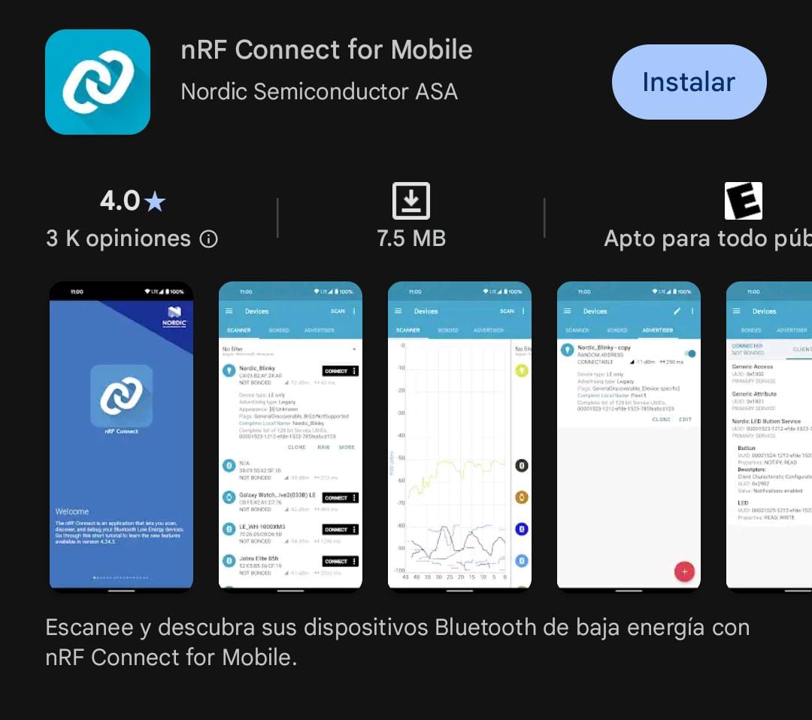
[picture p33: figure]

2. Conecte la maqueta a la alimentación eléctrica.
3. Encienda el tren y espere unos segundos hasta que el ESP32 (nombrado como “PRO-TORP”) comience a emitir su señal Bluetooth.
4. Active el Bluetooth en su celular y entre a la app.

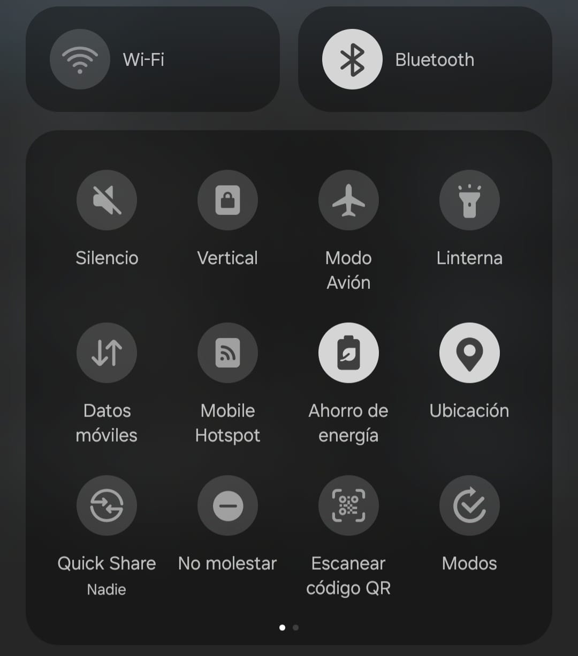
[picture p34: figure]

5. Una vez dentro, presione SCAN

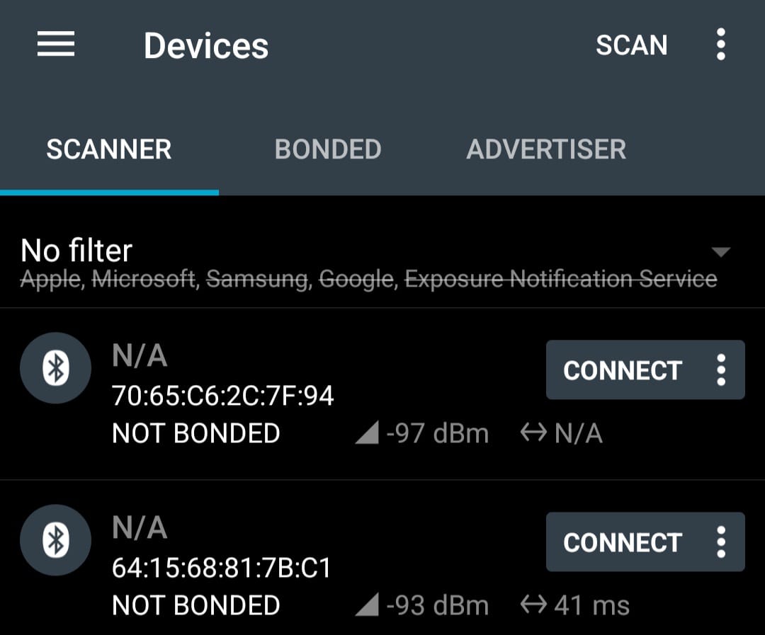
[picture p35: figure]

Busque el dispositivo "PROTORP ² ,cuando lo encuentre, seleccione CONNECT.

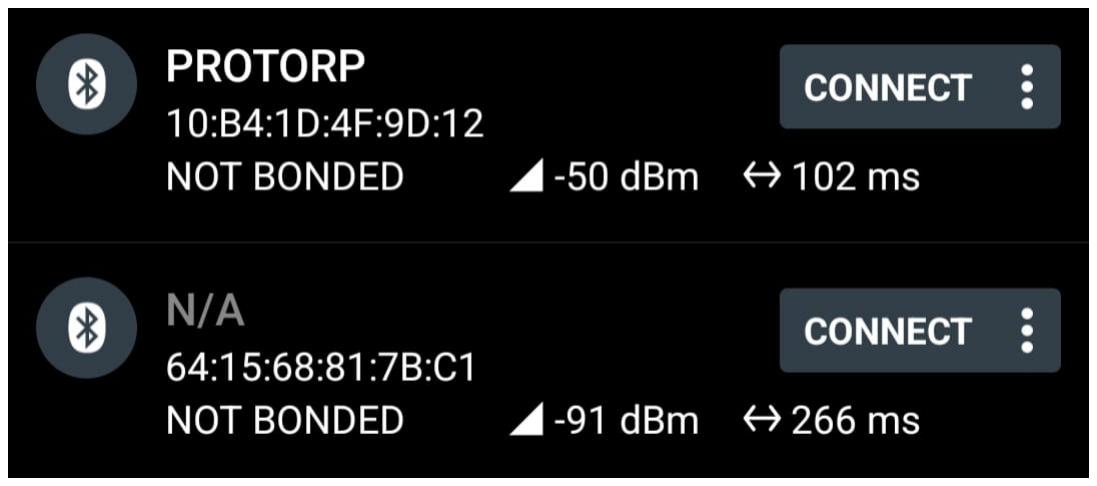
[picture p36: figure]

6. En la sección “Client”, seleccione Nordic UART Service.

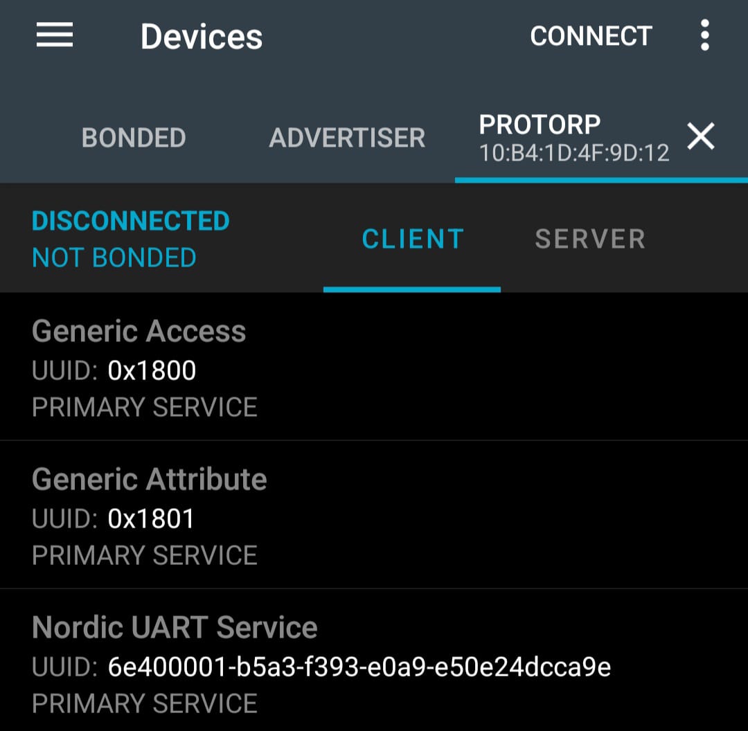
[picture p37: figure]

7. En “Nordic UART Service”, abra RX Characteristic y seleccione la flecha que apunta hacia arriba.

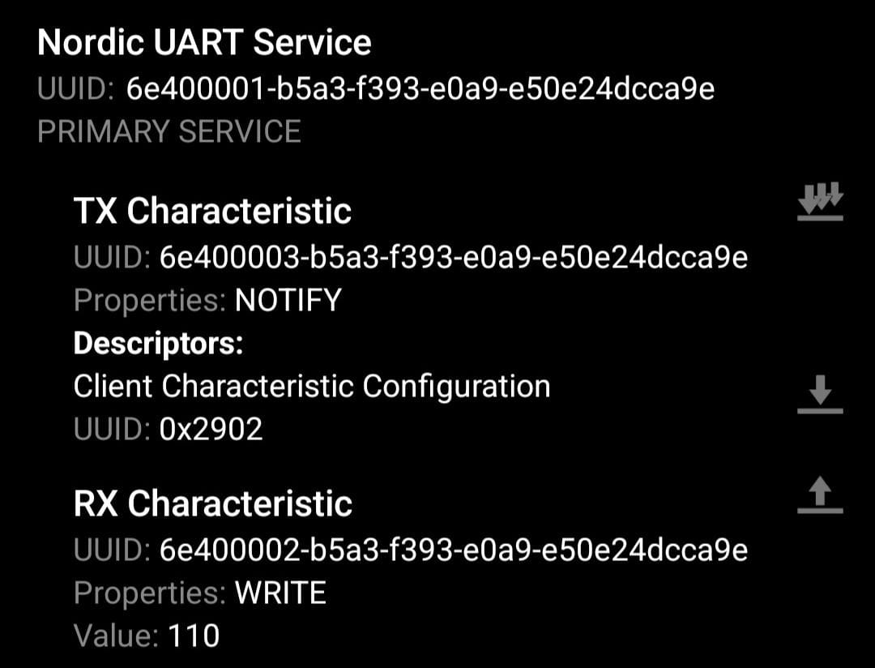
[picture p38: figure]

Le aparecerá la siguiente pantalla:

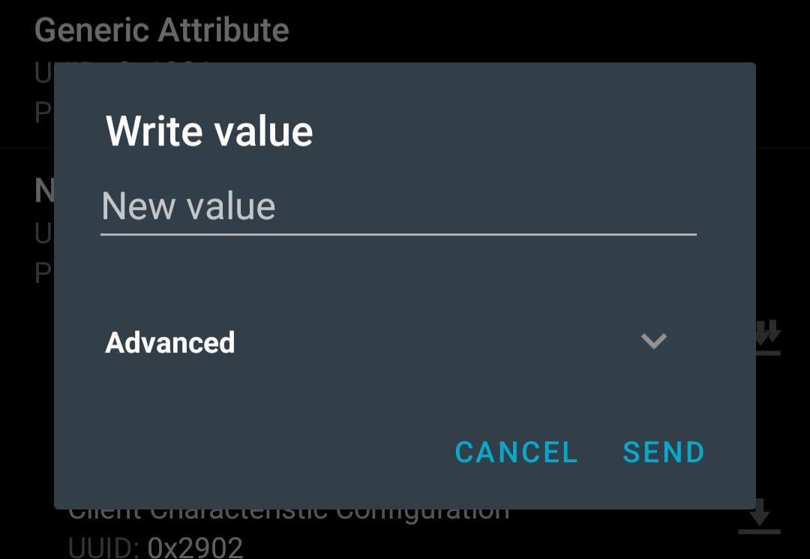
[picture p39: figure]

En "New Value", escriba el valor que desee y presione "SEND".
El sistema recibirá los datos y actuará en consecuencia:

El límite de velocidad para la locomotora es de 12 km/h (120) o 12V.

Si se envía un valor menor, el tren seguirá en línea recta.

Si se envía un valor entre 110 y 120, el tren reducirá su velocidad.

Si se envía un valor mayor a 120, el tren se detendrá.

De esta manera, se puede controlar la velocidad o la dirección del tren sin necesidad de tocar físicamente la maqueta. En caso de pérdida de conexión, el tren se detendrá automáticamente por seguridad.

## 5. Problemas o fallas comunes

Durante la operación pueden presentarse algunos inconvenientes menores:

Los LEDs no encienden: revisar polaridad o conexión al controlador.

El tren no se mueve: verificar la conexión Bluetooth y la alimentación del motor.

El mímico no responde: comprobar la comunicación entre la Raspberry y los módulos ESP32.

Se recomienda limpiar las vias con virulana y alcohol cada cierto tiempo, para evitar que se occiden y que el tren pueda circular correctamente sobre ellas.

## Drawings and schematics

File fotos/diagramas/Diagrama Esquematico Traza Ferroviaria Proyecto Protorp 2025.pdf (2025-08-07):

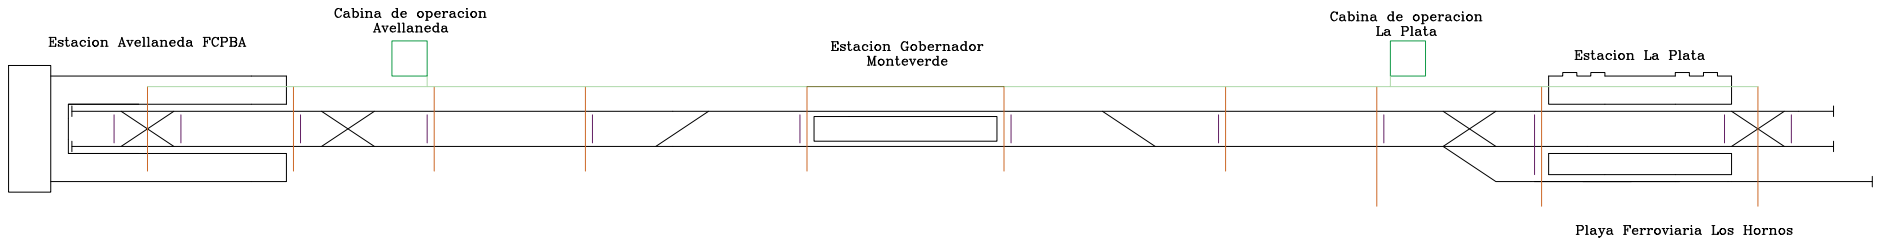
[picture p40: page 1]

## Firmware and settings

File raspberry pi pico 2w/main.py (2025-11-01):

import urequests as requests
import time
import machine
from machine import Pin, UART
import network
import json

SEGMENT_ID = 1

WIFI_SSID = "Cooperadora Profesores"
WIFI_PASSWORD = "Profes_IMPA_2022"

SERVER_IP = "192.168.1.138" 
SERVER_PORT = 5000
BASE_URL = f"http://{SERVER_IP}:{SERVER_PORT}"

PIN_SENSOR = 15

SEMAFORO_1 = {
    'ROJO': Pin(21, Pin.OUT), 
    'AMARILLO': Pin(20, Pin.OUT), 
    'VERDE': Pin(19, Pin.OUT)
}
SEMAFORO_2 = {
    'ROJO': Pin(18, Pin.OUT), 
    'AMARILLO': Pin(17, Pin.OUT), 
    'VERDE': Pin(16, Pin.OUT)
}

uart0 = UART(0, baudrate=9600, tx=Pin(0), rx=Pin(1))
uart1 = UART(1, baudrate=9600, tx=Pin(4), rx=Pin(5))
UARTS = [uart0, uart1]

sensor_ocupacion = Pin(PIN_SENSOR, Pin.IN, Pin.PULL_UP)
wlan = network.WLAN(network.STA_IF)

def connect_wifi():
    wlan.active(True)
    if not wlan.isconnected():
        wlan.connect(WIFI_SSID, WIFI_PASSWORD)
        max_wait = 10
        print(f"Intentando conectar a {WIFI_SSID}...")
        while max_wait > 0 and not wlan.isconnected():
            time.sleep(1)
            print('.', end='')
            max_wait -= 1

    if not wlan.isconnected():
        print("\n Conexión fallida. Reiniciando en 5s.")
        time.sleep(5)
        machine.reset()
    else:
        status = wlan.ifconfig()
        print("\n Conexión exitosa.")
        print('IP local:', status[0])

def get_loco_data():
    for uart in UARTS:
        if uart.any():
            try:
                line = uart.readline()
                if line:
                    data_str = line.decode('utf-8').strip()
                    data = json.loads(data_str)
                    loco_id = data.get('id', 0)
                    loco_speed = data.get('vel', 0)
                    print(f"  [UART Recibido en {uart.init(None)}] ID: {loco_id}, Vel: {loco_speed}")
                    return loco_id, loco_speed
            except Exception as e:
                print(f" Error al decodificar UART/JSON en {uart.init(None)}: {e}. Limpiando buffer.")
                while uart.any():
                    uart.read(1)
                time.sleep_ms(10)
    return 0, 0

def get_preceding_status(preceding_id):
    if preceding_id < 1:
        return "LIBRE"

    url = f"{BASE_URL}/get_segment_next_status/{preceding_id}"
    try:
        response = requests.get(url)
        status_next = response.json().get('status_next', 'LIBRE')
        response.close()
        return status_next
    except Exception as e:
        print(f" Error al consultar tramo anterior ({preceding_id}): {e}")
        return "LIBRE"

def send_update(status_real, status_next, loco_id, loco_speed):
    url = f"{BASE_URL}/update_segment"
    payload = {
        "segment_id": SEGMENT_ID,
        "status_real": status_real,
        "status_next": status_next,
        "loco_id": loco_id,
        "loco_speed": loco_speed,
    }
    
    try:
        response = requests.post(url, json=payload)
        
        if response.status_code == 200:
            print(f"  [HTTP Enviado] Real: {status_real}, Next: {status_next}")
        else:
            print(f" Error Mímico ({response.status_code}): {response.text}")
        
        response.close()
        
    except Exception as e:
        print(f" Error de red HTTP al enviar estado: {e}")

def determine_security_status(status_real):
    if status_real == 'OCUPADO':
        return 'BLOQUEADO'
    else:
        return 'LIBRE'

def actualizar_semaforos(nombre_estado):
    for semaforo in [SEMAFORO_1, SEMAFORO_2]:
        semaforo['ROJO'].value(0)
        semaforo['AMARILLO'].value(0)
        semaforo['VERDE'].value(0)

        if nombre_estado == 'LIBRE':
            semaforo['VERDE'].value(1)
        elif nombre_estado == 'PRECAUCION':
            semaforo['AMARILLO'].value(1)
        elif nombre_estado == 'BLOQUEADO' or nombre_estado == 'OCUPADO':
            semaforo['ROJO'].value(1)

def main_loop():
    print(f"--- Tramo Fijo ID: {SEGMENT_ID} INICIADO ---")
    
    connect_wifi()
    
    preceding_id = SEGMENT_ID - 1
    
    while True:
        is_occupied = not sensor_ocupacion.value()
        status_real = 'OCUPADO' if is_occupied else 'LIBRE'
        
        loco_id, loco_speed = get_loco_data()
        
        preceding_status = get_preceding_status(preceding_id)
        
        status_next = determine_security_status(status_real)
        
        actualizar_semaforos(preceding_status)
        
        if loco_id != 0:
            signal_to_loco = json.dumps({"signal": preceding_status}) + "\n"
            for uart in UARTS:
                uart.write(signal_to_loco.encode('utf-8'))
            print(f"  [UART Enviado] Señal a Locomotora {loco_id} en ambos puertos: {preceding_status}")
        
        send_update(status_real, status_next, loco_id, loco_speed)

        time.sleep(0.5)

try:
    main_loop()
except Exception as e:
    print(f"FATAL ERROR en main_loop: {e}")
    time.sleep(5)
    machine.reset()

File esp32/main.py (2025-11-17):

import time
from machine import Pin, PWM, UART
import bluetooth
from ble_simple_peripheral import BLESimplePeripheral

PIN_ENA = 4
PIN_IN1 = 3
PIN_IN2 = 2

pwm = PWM(Pin(PIN_ENA))
pwm.freq(1000)
dir1 = Pin(PIN_IN1, Pin.OUT)
dir2 = Pin(PIN_IN2, Pin.OUT)

PWM_MIN_IMPULSO = 30
VEL_MAX_HARDWARE = 100

uart_loc = UART(1, baudrate=115200, tx=Pin(21), rx=Pin(20))

ble = bluetooth.BLE()
sp = BLESimplePeripheral(ble, name="PROTORP")

vel_deseada = 0
velocidad_actual = 50
direccion = 1
senal_seguridad = 'C'

def set_motor_speed(vel):
    vel_abs = abs(vel)
    if vel > 0:
        dir1.value(1)
        dir2.value(0)
    elif vel < 0:
        dir1.value(0)
        dir2.value(1)
    else:
        dir1.value(0)
        dir2.value(0)
        pwm.duty(0)
        return

    if vel_abs > 0 and vel_abs < PWM_MIN_IMPULSO:
        vel_a_usar = PWM_MIN_IMPULSO
    else:
        vel_a_usar = vel_abs

    duty = int(min(vel_a_usar, VEL_MAX_HARDWARE) * 1023 / 100)
    pwm.duty(duty)

def on_rx(data):
    global vel_deseada, direccion, velocidad_actual
    try:
        message = data.decode().strip()
        print(f"Comando: {message}")
        
        if message == 'F':
            direccion = 1
            vel_deseada = velocidad_actual
            print("Adelante")
        elif message == 'B':
            direccion = -1
            vel_deseada = -velocidad_actual
            print("Atras")
        elif message == 'S':
            vel_deseada = 0
            print("Stop")
        elif message.isdigit():
            speed_val = int(message)
            if 0 <= speed_val <= 100:
                velocidad_actual = speed_val
                vel_deseada = speed_val * direccion
                print(f"Velocidad: {speed_val}%")
                
    except Exception as e:
        print(f"Error: {e}")

sp.on_write(on_rx)

def receive_security_signal():
    global senal_seguridad
    if uart_loc.any():
        try:
            data = uart_loc.readline()
            if data:
                signal = data.decode('utf-8').strip()
                if signal in ('A', 'B', 'C'):
                    senal_seguridad = signal
        except:
            pass

def send_speed_to_raspberry():
    mensaje = f"{vel_deseada}\n"
    try:
        uart_loc.write(mensaje.encode('utf-8'))
    except:
        pass

print("PROTORP INICIADO")

while True:
    receive_security_signal()
    send_speed_to_raspberry()
    
    if senal_seguridad == 'A':
        vel_aplicada = 0
        estado = "ROJO"
    elif senal_seguridad == 'B':
        vel_limit = 30
        if abs(vel_deseada) > vel_limit:
            vel_aplicada = int((vel_deseada / abs(vel_deseada)) * vel_limit)
        else:
            vel_aplicada = vel_deseada
        estado = "AMARILLO"
    else:
        vel_aplicada = vel_deseada
        estado = "VERDE"

    set_motor_speed(vel_aplicada)
    print(f"Estado: {estado} | Vel: {vel_deseada} | Motor: {vel_aplicada}")
    time.sleep_ms(1000)

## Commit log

2025-06-27 STL´s
    [señalizacion ferroviaria.stl]
2025-07-04 segunda version de la pagina web
    subimos la segunda version de la pagina web
2025-07-04 Update index.html
    codigo html de la pagina web
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2025-07-04 codigo html de la pagina.html
    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
2025-08-05 Modulo: comunicacion tren y via + semaforo
    Modulo para la comunicacion entre la locomotora y la via con el semaforo
2025-08-05 ATS/ATP
    Inicializa modulo de señalizacion ferroviaria con servo y leds
2025-08-05 agrega módulo de sensor virtual de ocupación con botón y LED para simulación ATS
2025-08-06 simula la ocupacion de la via con un led rojo
2025-08-06 inicializa modulo de señalizacion ferroviaria con servo y leds
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2025-08-08 añadimos un led verde que indica la via desocupada
2025-08-11 pruebas de leds con la raspberry pi pico en vscode
2025-08-18 script inicial de semaforos modificado en Thonny
    modificamos el script inicial de semaforos de control en Thonny
2025-08-18 lectura de sensores y logica de frenado automatico
    Simulación de 2 tramos de vía: semáforo, lectura simulada de sensores y lógica de frenado automático
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2025-08-21 Prueba de comunicación WiFi entre vía y locomotora
2025-08-28 comunicacion entre la raspberry de la locomotora y la via
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2025-09-16 subo la carpeta de los stls
    borre esta carpeta accidentalmente antes, asi que la subo de nuevo con el nuevo modelo de los semaforos
2025-09-19 carpeta STLs + semaforo con base circular
    [semaforo 2.0.2.stl.blend]
2025-09-19 subo STL del semaforo con base
    [semaforo 2.stl]
2025-10-01 Cliente MQTT funcional para Pico W
    version de prueba con MyMqtt para que la raspberry reciba los mensajes
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2025-10-02 modifico el codigo del ESP32 para incluir tambien el receptor RF de 433mhz
    modifico el codigo del ESP32 para incluir tambien el receptor RF de 433mhz
2025-10-02 borro este archivo para incluirlo en la carpeta de esp32
2025-10-02 subo nuevamente la carpeta de esp32
    subo esta carpeta de nuevo,junto con el codigo del esp32 de la locomotora mas el receptor rf de 433mhz, ya que la habia borrado accidentalmente
2025-10-02 modifico el codigo para incluir tambien leds y transmisor RF de 433mhz
2025-10-06 corrijo una pequeña falta de ortografia que hacia que el codigo no ande
2025-10-08 subo de nuevo la carpeta del esp32 con el codigo
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2025-10-08 subo la libreria necesaria para probar el codigo
2025-10-13 subo carpeta con el esquematico y diseño de las placas en Kicad
    [Esquematico de las placas.kicad_sch]
2025-10-13 subo STL con la base separada
    [semaforo 3.stl]
2025-10-13 subo el segundo modelo del semaforo
    [semaforo 2.stl]
2025-10-13 subo STL del primer semaforo hecho en el año
    [semaforo 1.stl]
2025-10-14 codigo actualizado para probar un tx y un rx
2025-10-14 creo carpeta wokwi
    creo carpeta para acomodar todas las simulaciones que se hicieron en Wokwi
2025-10-14 upload diagram.json
    cree una carpeta para subir todas las simulaciones que se hicieron en Wokwi
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2025-10-14 Delete Sensor de ocupacion directory
    esta carpeta fue reordenada en "Simulaciones Wokwi"
2025-10-15 subo el cuarto modelo del semaforo
    [semaforo 4.stl]
2025-10-15 update main.py
    codigo actualizado para que el esp32 mande una velocidad y reciba el estado del transmisor que va en la raspberry
2025-10-15 Update main.py
    codigo actualizado para recibir los datos de la locomotora (esp32) con su rx y que el tx le devuelva el estado al rx del esp32
2025-10-20 actualizo codigo para incluir puente PWM y Bluetooth
    actualizo el codigo del esp32 para incluir el control de motor con el driver L298N y control remoto con Bluetooth
2025-10-20 subo libreria ble_simple_peripheral
    esta libreria es necesaria para que el ESP32 sea reconocido como un dispositivo Bluetooth y para poder manejarlo mediante BT
2025-10-21 modifico el codigo del esp32 para aplicar la logica de control del motor
2025-10-21 actualizo libreria para poder recibir y mostrar mensajes en la app nRF connect
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2025-10-21 subo foto del proceso de impresion de los semaforos con sus bases en 3D
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2025-10-22 modifico el codigo para dejar de usar la libreria rf_simple y empezar a usar uart
    Refactor motor control logic and add UART communication.
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2025-11-16 tender del motor
    [plaqueta.stl]
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2025-11-17 Subo codigo final main.py
    este codigo esta hecho para recibir valores por bluetooth, ya sea una velocidad o una letra (F para avanzar, B para retroceder y S para parar automaticamente)
2025-11-17 Subo libreria ble_advertising.py
    Esta libreria es necesaria para que el ESP32 advierta que es un dispositivo bluetooth
2025-11-17 Subo la libreria ble_simple_peripheral.py
    Esta libreria es necesaria para que la ESP32 se anuncie como un dispositivo bluetooth y pueda recibir comandos
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2025-11-18 Subo video de una mini prueba del tren
    El tren tiene una ESP32, a la cual va conectada un driver. Al mandarle un valor por bluetooth se mueve. Nuestro problema fue que le mandamos cualquier valor y solo se mueve por un corto periodo de tiempo
2025-11-25 Subo video de prueba de semaforo
    El semaforo cuenta con un transmisor y un receptor de rf433mhz. El TX envia un 1 como un dato constantemente y el receptor al recibirlo cambia el led de verde a rojo
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
